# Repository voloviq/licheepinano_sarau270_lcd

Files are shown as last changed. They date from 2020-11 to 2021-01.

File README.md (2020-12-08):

# licheepinano_sarau270_lcd
LicheePi Nano Sara U270 Development Board

3D View of Board

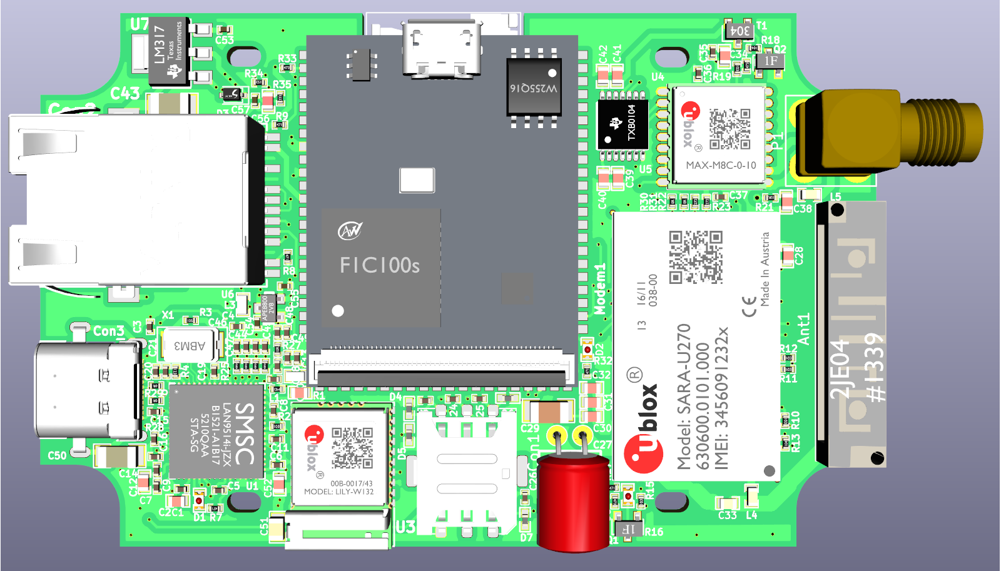
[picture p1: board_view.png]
3D View


PCB footprint is desinged for R19-2 SCI package

https://www.tme.eu/pl/details/absp-19/obudowy-uniwersalne/sci/r19-2/

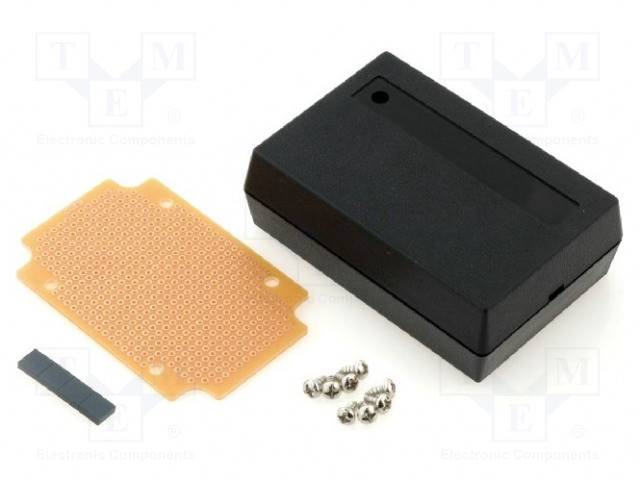
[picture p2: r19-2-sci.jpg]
Package


### Limitation

GSM antenna is not well designed. In this pcb footprint it can be difficult or impossible to do it well. To achieve maximum performance use SMD connector with external antenna.

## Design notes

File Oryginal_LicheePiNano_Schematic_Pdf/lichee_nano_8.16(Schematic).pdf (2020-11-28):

LCD | DDR | CSI

## SDC0

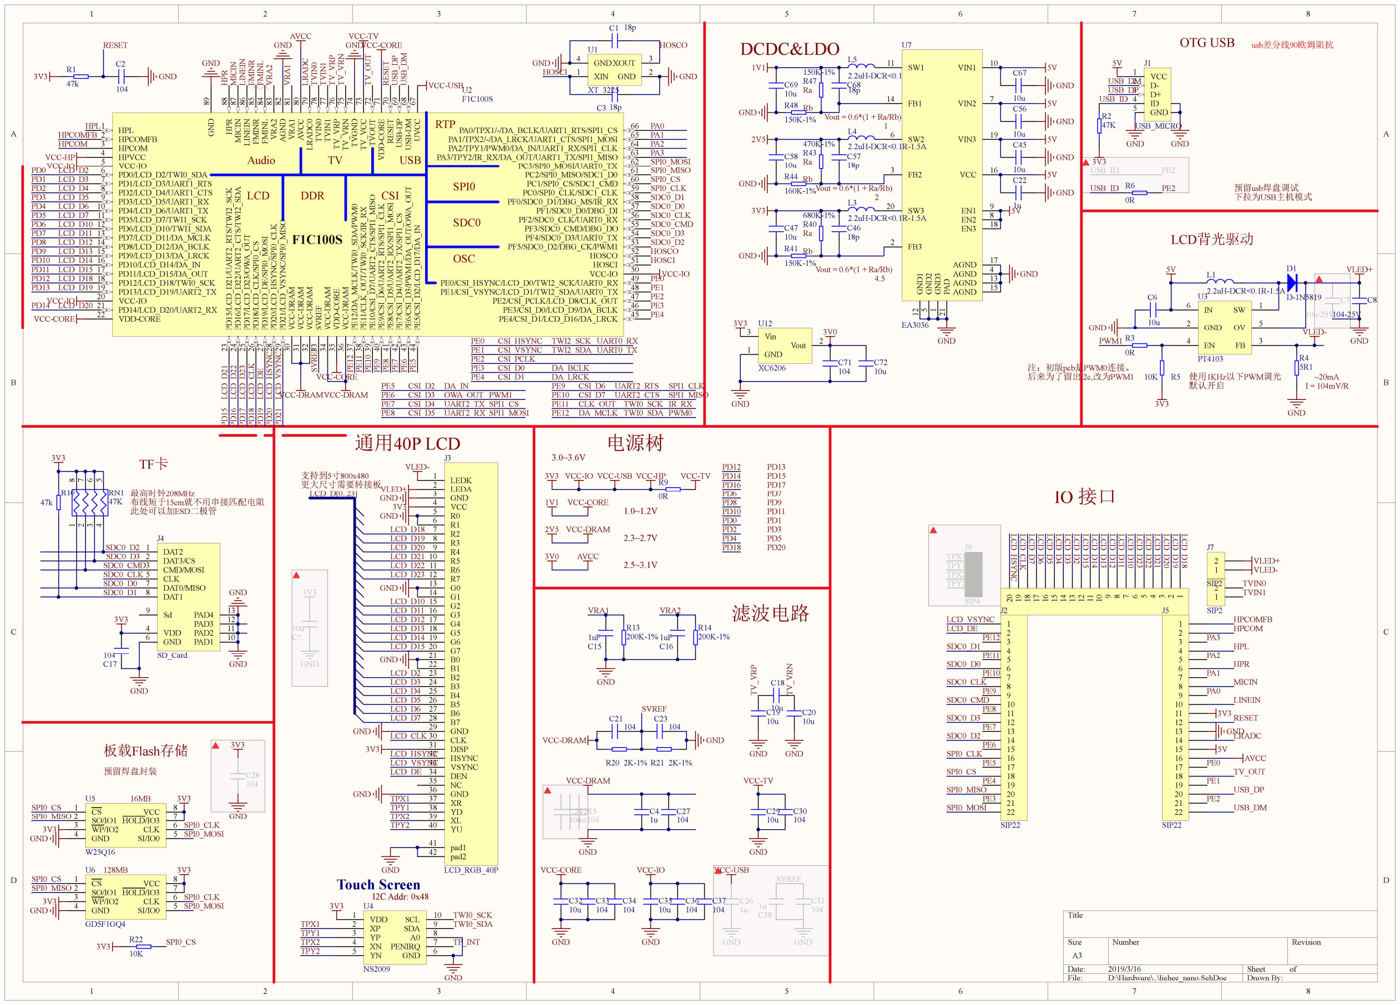
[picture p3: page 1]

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
Title

Size | Number | | Revision
A3
Date: | 2019/3/16 | Sheet | of
File: | D:\Hardware\..\lichee_nano.SchDoc | Drawn By:

HPL 1
HPCOMFB 2
HPCOM 3
HPVCC 4
VCC-IO 5
PD0/LCD_D2/TWI0_SDA 6
PD1/LCD_D3/UART1_RTS 7
PD2/LCD_D4/UART1_CTS 8
PD3/LCD_D5/UART1_RX 9
PD4/LCD_D6/UART1_TX 10
PD5/LCD_D7/TWI1_SCK 11
PD6/LCD_D10/TWI1_SDA 12
PD7/LCD_D11/DA_MCLK 13
PD8/LCD_D12/DA_BCLK 14
PD9/LCD_D13/DA_LRCK 15
PD10/LCD_D14/DA_IN 16
PD11/LCD_D15/DA_OUT 17
PD12/LCD_D18/TWI0_SCK 18
PD13/LCD_D19/UART2_TX 19
VCC-IO 20
PD14/LCD_D20/UART2_RX 21
VDD-CORE 22 | PD¹⁵/LCD_D²¹/UART²_RTS/TWI2_SCK 23 PD¹⁶/LCD_D²²/UART²_CTS/TWI2_SDA 24 PD¹⁷/LCD_D²³/OWA_OUT 25 PD¹⁸/LCD_CLK/SPI0_CS 26 PD¹⁹/LCD_DE/SPI0_MOSI 27 PD²⁰/LCD_HSYNC/SPI0_CLK 28 PD²¹/LCD_VSYNC/SPI0_MISO 29 VCC⁻DRAM 30 VCC⁻DRAM 31 VCC⁻DRAM 32 SVREF 33 VCC⁻DRAM 34 VDD⁻CORE 35 VCC⁻DRAM 36 PE¹²/DA_MCLK/TWI0_SDA/PWM⁰ 37 PE¹¹/CLK_OUT/TWI0_SCK/IR_RX 38 PE¹⁰/CSI_D⁷/UART²_CTS/SPI1_MISO 39 PE⁹/CSI_D⁶/UART²_RTS/SPI1_CLK 40 PE⁸/CSI_D⁵/UART²_RX/SPI1_MOSI 41 PE⁷/CSI_D⁴/UART²_TX/SPI1_CS 42 PE⁶/CSI_D³/PWM¹/DA_OUT/OWA_OUT 43 PE⁵/CSI_D²/LCD_D¹⁷/DA_IN 44
PE4/CSI_D1/LCD_D16/DA_LRCK | 45 PE3/CSI_D0/LCD_D9/DA_BCLK | 46 PE2/CSI_PCLK/LCD_D8/CLK_OUT | 47 PE1/CSI_VSYNC/LCD_D1/TWI2_SDA/UART0_TX | 48 PE0/CSI_HSYNC/LCD_D0/TWI2_SCK/UART0_RX | 49 VCC-IO | 50 HOSCI | 51 HOSCO | 52 PF5/SDC0_D2/DBG_CK/PWM1 | 53 PF4/SDC0_D3/UART0_TX | 54 PF3/SDC0_CMD/DBG_DO | 55 PF2/SDC0_CLK/UART0_RX | 56 PF1/SDC0_D0/DBG_DI | 57 PF0/SDC0_D1/DBG_MS/IR_RX | 58 PC0/SPI0_CLK/SDC1_CLK | 59 PC1/SPI0_CS/SDC1_CMD | 60 PC2/SPI0_MISO/SDC1_D0 | 61 PC3/SPI0_MOSI/UART0_TX | 62 PA3/TPY2/IR_RX/DA_OUT/UART1_TX/SPI1_MISO | 63 PA2/TPY1/PWM0/DA_IN/UART1_RX/SPI1_CLK | 64 PA1/TPX2/-/DA_LRCK/UART1_CTS/SPI1_MOSI | 65 PA0/TPX1/-/DA_BCLK/UART1_RTS/SPI1_CS | 66 UVCC ⁶⁷ USB⁻DM ⁶⁸ USB⁻DP ⁶⁹ RESET ⁷⁰ VDD⁻CORE ⁷¹ TVOUT ⁷² TV_VCC ⁷³ TVGND ⁷⁴ TV_VRN ⁷⁵ TV_VRP ⁷⁶ TVIN¹ ⁷⁷ TVIN⁰ ⁷⁸ LRADC⁰ ⁷⁹ AVCC ⁸⁰ VRA¹ ⁸¹ AGND ⁸² VRA² ⁸³ FMINL ⁸⁴ FMINR ⁸⁵ LINEIN ⁸⁶ MICIN ⁸⁷ HPR ⁸⁸ GND ⁸⁹

## OSC

## SPI0

## RTP

Audio | TV | USB

## F1C100S

U2
F1C100S

LEDK 1
LEDA 2
GND 3
VCC 4
R0 5
R1 6
R2 7
R3 8
R4 9
R5 10
R6 11
R7 12
G0 13
G1 14
G2 15
G3 16
G4 17
G5 18
G6 19
G7 20
B0 21
B1 22
B2 23
B3 24
B4 25
B5 26
B6 27
B7 28
GND 29
CLK 30
DISP 31
HSYNC 32
VSYNC 33
DEN 34
NC 35
GND 36
XR 37
YD 38
XL 39
YU 40

pad1 41
pad2 42

J3

LCD_RGB_40P

LCD_D2
LCD_D3
LCD_D4
LCD_D5
LCD_D6
LCD_D7

LCD_D10
LCD_D11
LCD_D12
LCD_D13
LCD_D14
LCD_D15

LCD_D18
LCD_D19
LCD_D20
LCD_D21
LCD_D22
LCD_D23

LCD_D[0..23] GND

3V3

GND

C?

10u

LCD_CLK

LCD_DE

LCD_HSYNC
LCD_VSYNC

TPX1

TPX2

TPY1

TPY2

GND

GND

VLED+

VLED-

# 通用40P LCD

GND

GND

GND

3V3

3V3

GND

支持到5寸800x480
更大尺寸需要转接板

LCD_D2
LCD_D3
LCD_D4
LCD_D5
LCD_D6
LCD_D7
LCD_D10
LCD_D11
LCD_D12
LCD_D13
LCD_D14
LCD_D15
LCD_D18
LCD_D19
LCD_D20 | LCD_D²¹ LCD_D²² LCD_D²³ LCD_CLK LCD_DE LCD_HSYNC LCD_VSYNC

VCC-IO

VCC-IO

VCC-IO

VCC-CORE

VCC-CORE

VCC-DRAMVCC-DRAM SVREF

VCC-CORE RESET USB_DP USB_DMGND

VCC-HP

HPL | HPR MICIN LINEIN FMINR FMINL VRA² | VRA¹ AVCCLRADC TVIN⁰ TVIN¹ TV_VRP TV_VRN

VCC-TVTV_OUT

PE0
PE1
PE2
PE3

PE4 PE¹² PE¹¹ PE¹⁰ PE⁹ PE⁸ PE⁷ PE⁶ PE⁵

HOSCO
HOSCI

SDC0_D0

SDC0_D1

SDC0_D2

SDC0_D3

SDC0_CLK
SDC0_CMD

SPI0_CLK

SPI0_CS

SPI0_MISO

SPI0_MOSI

HPCOMFB
HPCOM
XIN 1 | GND | 2
XOUT | 3 GND 4

U1

XT_3225

GND
GND

C3 18p

C1 18p

HOSCO

HOSCI

SDC0_CMD
SDC0_CLK
SDC0_D0
SDC0_D1

SDC0_D2
SDC0_D3

GND

GND

3V3

C17

104 ¹

2

34 58
7

6
RN1
47K

R10
47k

3V3

最高时钟208MHz
布线短于15cm就不用串接匹配电阻
此处可以加ESD二极管

## TF卡

GND

CS 1
SO/IO1 2
WP/IO2 3
GND 4 | SI/IO0 | 5
| CLK | 6
HOLD/IO3 | 7
VCC | 8

U5

W25Q16

SPI0_MISO

SPI0_MOSI

SPI0_CLK

SPI0_CS

CS 1
SO/IO1 2
WP/IO2 3
GND 4 | SI/IO0 | 5
| CLK | 6
HOLD/IO3 | 7
VCC | 8

U6

GD5F1GQ4

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
3V3 | SPI0_CS

16MB

128MB

## 板载Flash存储

预留焊盘封装

# DCDC&LDO

SW 1

GND 2

FB | 3 EN 4
OV | 5

IN 6

U3

PT4103

L1
2.2uH-DCR<0.1R-1.5A
C6

10u GND

D1

D-1N5819 C7

10u-25V

C8

| 104-25V VLED+

GND

10K R5
I = 104mV/R

R4
5R1

GND

VLED-

使用1KHz以下PWM调光 | ~20mA

## LCD背光驱动

5V

PWM1 R3
0R

R2
47K

usb差分线90欧姆阻抗

VCC 1
D- 2
D+ 3
ID 4
GND 5

J1

USB_MICRO

GND GND

USB_ID

预留usb焊盘调试
下拉为USB主机模式

# 电源树

3V3 VCC-IO

GND | GND

VCC-TV

1V1 VCC-CORE
1.0~1.2V

3.0~3.6V

VCC-USB

VCC-USB

2V5 VCC-DRAM
2.3~2.7V

3V0 AVCC
2.5~3.1V

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
PD10
PD11
PD12
PD13
PD14 | PD¹⁵ PD¹⁶ PD¹⁷ PD¹⁸ PD¹⁹ PD²⁰ PD²¹
PD0 | PD1
PD2 | PD3
PD4 | PD5
PD6 | PD7
PD8 | PD9
PD10 | PD11
PD12 | PD13
PD14 | PD15
PD16 | PD17

C2

104

3V3 | GND

RESET

GND

C15

1uF

R13
200K-1%
VRA1 | VRA2

C16

1uF

R14
200K-1%

R20 2K-1% R21 2K-1%

C21
104

C23
104
VCC-DRAM | GND

SVREF

SVREF

C31
104 C38

1u

GND

VCC-DRAM

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
VCC-CORE

C32
10u

C33
104

C34
104

GND

VCC-IO

C35
10u

C36
104

C37
104

GND

VCC-TV

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
GND | GND TV_VRP | TV_VRN

## OTG USB

# 滤波电路

# IO 接口

USB_DP

USB_DM

VCC-HP

R1
47k

R9
0R

SPI0_MISO

SPI0_MOSI

SPI0_CLK

SPI0_CS

1V1 | 5V

L5

# 2.2uH-DCR<0.1R-1.5A GND³

1

FB3 2

FB2 3

AGND 4 GND²

5

SW2 6

VIN2 | 7
EN2 | 8
EN1 | 9
VIN1 | 10 SW1 11 | GND¹ 12
AGND | 13

FB1 14

AGND | 15
VCC | 16
AGND | 17
EN3 | 18
VIN3 | 19
SW3 20 | PAD 21

U7

EA3036

R47

150K-1%
GND

C67

10u

C68 18p C69
10u Ra
5V Rb GND
GND Vout = 0.6*(1 + Ra/Rb)

C56

10u

R48
150K-1%
1
2V5 | 5V

L4
2.2uH-DCR<0.1R-1.5A
R43

470K-1%
GND

C45

10u

C57
18p

C58
10u Ra
5V Rb GND | Vout = 0.6*(1 + Ra/Rb) | GND
C22

1u

R44
160K-1%
2
3V3 | 5V

L3
2.2uH-DCR<0.1R-1.5A
R40

680K-1%
C46
18p

C47
10u Ra

Rb GND

R41
150K-1%
GND Vout = 0.6*(1 + Ra/Rb) 4.5

GND

3V0

C71
104

Vin 3

GND 1

Vout 2

U12

XC6206

3V3

C72
10u

GND

C26
1u

GND

VCC-USB

3V3

C28
104

GND

3V3 20 | 119 | 218 | 317 | 416 | 515 | 614 | 713 | 812 | 91110

J8

# SIP20LCD_HSYNC LCD_CLK

LCD_DE

LCD_VSYNC | LCD_D7 LCD_D6 LCD_D5 LCD_D4 LCD_D3 LCD_D2 LCD_D15 LCD_D14 LCD_D13 LCD_D12 LCD_D11 LCD_D10 LCD_D23 LCD_D22 LCD_D21 LCD_D20 LCD_D19 LCD_D18 PD18 | PD20

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
PE10
PE11
PE12

CSI_HSYNC TWI2_SCK UART0_RX CSI_VSYNC TWI2_SDA UART0_TX CSI_PCLK
CSI_D0
CSI_D1
CSI_D2
CSI_D3
CSI_D4
CSI_D5

CSI_D6
CSI_D7

DA_MCLK

CLK_OUT

DA_BCLK
DA_LRCK
DA_IN
OWA_OUT
UART2_TX SPI1_CS
UART2_RX SPI1_MOSI

UART2_RTS SPI1_CLK
UART2_CTS SPI1_MISO
TWI0_SCK
TWI0_SDA

IR_RX
PWM0

3V3

默认开启

PA0
PA1
PA2
PA3

USB_ID R6
0R

PE2

USB_ID | PE2

PE5

PE6

PE7

PE8

PE9

PE10

PE11

PE12

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
SDC0_D0

SDC0_D1

SDC0_D2

SDC0_D3

SDC0_CLK

SDC0_CMD

SPI0_CLK

SPI0_CS

SPI0_MISO

SPI0_MOSI

HPL

HPCOMFB
HPCOM

RESET

USB_DP

USB_DM

HPR

MICIN

LINEIN

AVCC

LRADC

TVIN0
TVIN1

TV_OUT

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
SIP22

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
SIP22

DAT2 1
DAT3/CS 2
CMD/MOSI 3

VDD 4

CLK 5

GND 6

DAT0/MISO 7
DAT1 8

Sd 9

PAD1 | 10 PAD2 | 11 PAD3 | 12 PAD4 | 13

J4

SD_Card

1

2

J6

SIP2

1

2

J7

SIP2

VLED+
VLED-

1

2

3

4

J9

SIP4

TPX1

TPX2

TPY1

TPY2

PWM1

注：初版pcb是PWM0连接。
后来为了留出i2c,改为PWM1

# Touch Screen

TP_INT

I2C Addr: 0x48

VDD 1
XP 2
YP 3
XN 4
YN 5 | GND | 6
| PENIRQ | 7
| A0 | 8
SDA | 9
SCL | 10

U4

NS2009

3V3

TPX1
TPY1
TPX2

GND

TPY2

TWI0_SCK
TWI0_SDA

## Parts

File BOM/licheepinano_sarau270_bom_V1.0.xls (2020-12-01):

Component | Description | Part | References | Value | Footprint | Quantity Per PCB | Notice | Supplier Part Number | Supplier | URL | Manufacturer Part Number | Manufacturer | LCSC Part # (optional)
1 | Embedded Dielectric Quad Band Antenna | MEE04 | Ant1 | MEE04 | MEE04 | 1 |  | MEE04 | Microdis
2 | 100nF, 16V, X5R, 10%, -40°C to +85°C | 100nF/16V | C52 | 100nF/16V | 0603 | 1
3 | 100nF, 50V, X5R, 10%, -40°C to +85°C | 100nF/50V | C2 C5 C6 C8 C9 C11 C12 C13 C14 C15 C16 C17 C18 C19 C20 C21 C35 C36 C37 | 100nF/50V | 0402 | 19 |  | CL05B104KO5NNNC | TME | https://www.tme.eu/pl/details/cl05b104ko5nnnc/kondensatory-mlcc-smd-0402/samsung/ | CL05B104KO5NNNC | SAMSUNG
4 | 100nF, 50V, X5R, 10%, -40°C to +85°C | 100nF/50V | C28 C30 C31 C32 C40 C42 | 100nF/50V | 0603 | 6 |  | CL10B104JB8NNNC | TME | https://www.tme.eu/pl/details/cl10b104jb8nnnc/kondensatory-mlcc-smd-0603/samsung/ | CL10B104JB8NNNC | SAMSUNG
5 | 10pF, 50V, X5R, 10%, -40°C to +85°C | 10pF/50V | C33 | 10pF/50V | 0603 | 1 |  | CL10C100JB8NNNC | TME | https://www.tme.eu/pl/details/cl10c100jb8nnnc/kondensatory-mlcc-smd-0603/samsung/ | CL10C100JB8NNNC | SAMSUNG
6 | 10uF, 10V, X5R, 10%, -40°C to +85°C | 10uF/10V | C56 | 10uF/10V | 0603 | 1 |  | C0603C106M9PAC | TME | https://www.tme.eu/pl/details/c0603c106m9pac/kondensatory-mlcc-smd-0603/kemet/c0603c106m9pactu/ | C0603C106M9PACTU | KEMET | C162265
7 | 10uF, 16V, X5R, 10%, -40°C to +85°C | 10uF/16V | C51 | 10uF/16V | 0805 | 1
8 | 15pF, 50V, X5R, 10%, -40°C to +85°C | 15pF/50V | C44 C45 C46 C47 | 15pF/50V | 0402 | 4 |  | GRM1555C1H150JA01D | TME | https://www.tme.eu/pl/details/grm1555c1h150ja01d/kondensatory-mlcc-smd-0402/murata/ | GRM1555C1H150JA01D | MURATA
9 | 1nF, 2kV, X7R, 10%, -40°C to +85°C | 1nF/2kV | C43 C50 | 1nF/2kV | 1206 | 2 |  | CC1206KKX7RD102 | TME | https://www.tme.eu/pl/details/cc1206kkx7rd102/kondensatory-mlcc-smd-1206/yageo/cc1206kkx7rdbb102/ | CC1206KKX7RDBB102 | YAGEO
10 | 1uF, 10V, X5R, 10%, -40°C to +85°C | 1uF/10V | C53 C54 C55 C57 | 1uF/10V | 0402 | 4 |  | CL05A105KP5NNNC | TME | https://www.tme.eu/pl/details/cl05a105kp5nnnc/kondensatory-mlcc-smd-0402/samsung/ | CL05A105KP5NNNC | SAMSUNG
11 | 1uF, 6.3V, X5R, 10%, -40°C to +85°C | 1uF/6.3V | C10 C34 C38 C39 C41 | 1uF/6V3 | 0603 | 5 |  | CL10B105KO8NNNC | TME | https://www.tme.eu/pl/details/cl10b105ko8nnnc/kondensatory-mlcc-smd-0603/samsung/ | CL10B105KO8NNNC | SAMSUNG
12 | 220uF, 6.3, -40°C to +85°C, Polymer Capacitor | 220uF/6.3V | C27 | 220uF/6V3 | Fi 8mm x length 8mm | 1 |  | 710-870025174002 | Mouser | https://pl.mouser.com/ProductDetail/Wurth-Elektronik/870025174002?qs=0KOYDY2FL28WZrZvNjpH0g%3D%3D | 870025174002 | Wurth Elektronik
13 | 22nF, 25V, X5R, 10%, -40°C to +85°C | 22nF/25v | C48 C49 | 22nF/25V | 0402 | 2 |  | GRM155R71E223KA61D | TME | https://www.tme.eu/pl/details/grm155r71e223ka61d/kondensatory-mlcc-smd-0402/murata/ | GRM155R71E223KA61D | MURATA
14 | 30pF, 50V, X5R, 10%, -40°C to +85°C | 30pF/50V | C3 C4 | 30pF/50V | 0402 | 2 |  | C0402C300J5GAC | TME | https://www.tme.eu/pl/details/c0402c300j5gac/kondensatory-mlcc-smd-0402/kemet/c0402c300j5gactu/ | C0402C300J5GACTU | KEMET
15 | 4.7uF, 6.3V, X5R, 10%, -40°C to +85°C | 4.7uF/6.3V | C1 C7 | 4.7uF/6V3 | 0603 | 2 |  | CL10A475KQ8NNNC | TME | https://www.tme.eu/pl/details/cl10a475kq8nnnc/kondensatory-mlcc-smd-0603/samsung/ | CL10A475KQ8NNNC | SAMSUNG
16 | 47pF, 50V, X5R, 10%, -40°C to +85°C | 47pF/50V | C23 C24 C25 C26 | 47pF/50V | 0402 | 4 |  | 0402N470J500CT | TME | https://www.tme.eu/pl/details/0402n470j500ct/kondensatory-mlcc-smd-0402/walsin/ | 0402N470J500CT | WALSIN
17 | 47uF, 6.3V, X5R, 20%, -40°C to +85°C MLCC | 47uF/6.3V | C29 | 47uF/6V3 | 1206 | 1 |  | 810-C3216X5R0J476M | Mouser | https://pl.mouser.com/ProductDetail/TDK/C3216X5R0J476M160AC?qs=sGAEpiMZZMvsSlwiRhF8qsDt8B2LujiHL4PsWRWliZg%3D | C3216X5R0J476M160AC | TDK
18 | GCT Nano SIM Holder 6 contacts | SIM8050-6-0-14-01-A | Con1 | SIM8050-6-0-14-01-A | SMD Nano Siim | 1 |  | 2344457 | Farnell | https://uk.farnell.com/gct-global-connector-technology/sim8050-6-0-14-01-a/connector-nano-sim-card-6pos-smt/dp/2344457 | SIM8050-6-0-14-01-A. | GCT (GLOBAL CONNECTOR TECHNOLOGY)
19 | WR-COM USB 3.1 Type C Receptacle Horizontal Mid-Mount THR / SMT 1.6 mm | USB C | Con3 | USB_C_Wurth_632723130112 | USB_C | 1 |  | 710-632723130112 | Mouser | https://pl.mouser.com/ProductDetail/Wurth-Elektronik/632723130112?qs=2WXlatMagcEknienHxbwUw%3D%3D | 632723130112 | Wurth Elektronik
20 | LAN-Transformer WE-RJ45LAN 10/100BaseT - 40°C to + 85°C | WE-RJ45 | Con2 | WE-RJ45_7498011122AR | WE-RJ45 | 1 |  | 710-7498011122AR | Mouser | https://pl.mouser.com/ProductDetail/Wurth-Elektronik/7498011122AR?qs=GBLSl2AkiruAAlB45OgRtA%3D%3D | 7498011122AR | Wurth
21 | Red Led diode 630nm 20mA 200...350mcd 120° -40°C to +85°C | KPG-1608SURKC-T | D1 D2 D8 | KPG-1608SURKC-T | 0603 | 3 |  | KPG-1608SURKC-T | TME | https://www.tme.eu/pl/details/kpg-1608surkc-t/diody-led-smd-kolorowe/kingbright-electronic/ | KPG-1608SURKC-T | KINGBRIGHT ELECTRONIC
22 | Schottky Barrier Diode 500mA | NSR0530H-D | D3 | NSR0530H-D | SOD323 | 1
23 | ESD Protector, Overvoltage Protection Device | PESD0402-140 | D4 D5 D6 D7 | PESD0402-140 | 0402 | 4 |  | 650-PESD0402-140 | Mouser | https://pl.mouser.com/ProductDetail/Littelfuse/PESD0402-140?qs=y1EbU1W0OrtTHVfbQV6MTg%3D%3D | PESD0402-140 | Littelfuse
24 | LiangHaoCai 2.4" LED Display with SPI Interface | LiangHaoCai Display | DIS1 | LiangHaoCai_Ili9341_spi | Ffc/Fpc solder type | 1
25 | 39nH, 300mA, 0.6Ω, 10%, -40°C to +85°C | 39nH | L4 L5 | 39nH | 0603 | 2 |  | 963-HK160839NH-T | Mouser | https://pl.mouser.com/ProductDetail/Taiyo-Yuden/HK160839NH-T | HK160839NH-T | Taiyo Yuden
26 | Z=600Ohm,Load=0.3A,R=0.7Ohm, Temp=-55C+125C, EMI Suppression Filters EMIFIL | BLM15HG601SN1D | L6 | BLM15HG601SN1D | 0402 | 1
27 | Ferrite Bead 600Ω 1A 200mΩ - 55℃ +125℃ 0603 | LCBA-601 | L1 L3 | LCBA-601 | LCBA-601 | 2 |  | LCBA-601 | TME | https://www.tme.eu/pl/details/lcba-601/ferryty-koraliki/ferrocore/ | LCBA-601 | FERROCORE
28 | SARA-U2 series 3.75G HSPA Cellular Modules | Sara_U270 | Modem1 | Sara_U270 | LGA | 1
29 | Adam Tech SMA Jack Right Angle THT Connector | RF2-03E-T-00-50-G | P1 | RF2-03E-T-00-50-G | THT-SMA | 1 |  | RF2-03E-T-00-50-G | TME | https://www.tme.eu/pl/details/rf2-03e-t-00-50-g/zlacza-sma-smb-smc/adam-tech/ | RF2-03E-T-00-50-G | ADAM TECH
30 | UCE=45V, Ic=100mA, P=250mW, -40°C to +85°C NPN Transistor | BC847B | Q1 Q2 | BC847B | SOT23 | 2 |  | BC847BE6327 | TME | https://www.tme.eu/pl/details/bc847be6327/tranzystory-npn-smd/infineon-technologies/ | BC847BE6327 | INFINEON TECHNOLOGIES
31 | 0Ω 0.063W, 10%, -40°C to +85°C | 0R | R28 R29 R30 R31 | 0R | 0402 | 4 | R30, R31 Not mount | CRCW04020000Z0E | TME | https://www.tme.eu/pl/details/crcw04020000z0e/rezystory-smd-0402/vishay/crcw04020000z0ed/ | CRCW04020000Z0ED | VISHAY | C325378
32 | 100kΩ 0.063W, 10%, -40°C to +85°C | 100k | R13 R18 | 100k | 0402 | 2 |  | RC0402FR-07100K | TME | https://www.tme.eu/pl/details/rc0402fr-07100k/rezystory-smd-0402/yageo/ | RC0402FR-07100K | YAGEO
33 | 10Ω 0.063W, 10%, -40°C to +85°C | 10R | R21 R27 | 10R | 0402 | 2 |  | SMD0402-10R-1% | TME | https://www.tme.eu/pl/details/smd0402-10r-1%2525/rezystory-smd-0402/royal-ohm/0402wgf100jtce/ | 0402WGF100JTCE | ROYAL OHM
34 | 10kΩ 0.063W, 10%, -40°C to +85°C | 10k | R2 R10 R11 R12 R15 R19 | 10k | 0402 | 6 |  | SMD0402-10K-1% | TME | https://www.tme.eu/pl/details/smd0402-10k-1%2525/rezystory-smd-0402/royal-ohm/0402wgf1002tce/ | 0402WGF1002TCE | ROYAL OHM
35 | 12.4kΩ 1% 0.063W, 10%, -40°C to +85°C | 12k4 | R1 | 12k/1% | 0402 | 1 |  | 603-RC0402FR-0712K4L | Mouser | https://pl.mouser.com/ProductDetail/Yageo/RC0402FR-0712K4L | RC0402FR-0712K4L | Yageo
36 | 12kΩ 1% 0.063W, 10%, -40°C to +85°C | 12k | R4 | 12k/1% | 0402 | 1 |  | 279-CRGCQ0402F12K | Mouser | https://pl.mouser.com/ProductDetail/TE-Connectivity-Holsworthy/CRGCQ0402F12K | CRGCQ0402F12K | TE Connectivity / Holsworthy
37 | 1MΩ 0.063W, 10%, -40°C to +85°C | 1M | R3 | 1M | 0402 | 1 |  | SMD0402-1M-1% | TME | https://www.tme.eu/pl/details/smd0402-1m-1%2525/rezystory-smd-0402/royal-ohm/0402wgf1004tce/ | 0402WGF1004TCE | ROYAL OHM
38 | 1.5kΩ 0.063W, 10%, -40°C to +85°C | 1k5 | R34 | 1k5 | 0402 | 1 |  | SMD0402-1K5-1% | TME | https://www.tme.eu/pl/details/smd0402-1k5-1%2525/rezystory-smd-0402/royal-ohm/0402wgf1501tce/ | 0402WGF1501TCE | ROYAL OHM
39 | 2.7kΩ 0.063W, 10%, -40°C to +85°C | 2k7 | R22 R23 | 2k7 | 0402 | 2 |  | CRCW04022K70FKTDBC | TME | https://www.tme.eu/pl/details/crcw04022k70fktdbc/rezystory-smd-0402/vishay/ | CRCW04022K70FKTDBC | VISHAY
40 | 4.7kΩ 0.063W, 10%, -40°C to +85°C | 3k3 | R35 | 3k3 | 0402 | 1 |  | SMD0402-3K3-1% | TME | https://www.tme.eu/pl/details/smd0402-3k3-1%2525/rezystory-smd-0402/royal-ohm/0402wgf3301tce/ | 0402WGF3301TCE | ROYAL OHM
41 | 470Ω 0.063W, 10%, -40°C to +85°C | 470R | R7 R8 R9 R17 R32 | 470R | 0402 | 5 |  | SMD0402-470R-1% | TME | https://www.tme.eu/pl/details/smd0402-470r-1%25/rezystory-smd-0402/royal-ohm/0402wgf4700tce/ | 0402WGF4700TCE | ROYAL OHM
42 | 47kΩ 0.063W, 10%, -40°C to +85°C | 47k | R16 R20 R33 | 47k | 0402 | 3 |  | CQ0402-47K-1% | TME | https://www.tme.eu/pl/details/cq0402-47k-1%2525/rezystory-smd-0402/royal-ohm/cq02wgf4702tce/ | CQ02WGF4702TCE | ROYAL OHM
43 | 49.9Ω 1% 0.063W, 10%, -40°C to +85°C | 49R9 | R14 R24 R25 R26 | 49R9/1% | 0402 | 4
44 | LicheePiNano board | LicheePiNano | SOM1 | LicheePiNano | SOM | 1 |  | LicheePi Nano | Seeed | https://www.seeedstudio.com/LicheePi-Nano-ARM926EJS-SoC-Development-Board-16M-Flash-p-2892.html | LicheePi Nano | SiPeed
45 | Uds=-20V; Id=-2,4A; 0,5W P-Channel Specified PowerTrench MOSFET | FDN304P | T1 | FDN304P | SOT23 | 1 |  | 512-FDN304P | Mouser | https://pl.mouser.com/ProductDetail/ON-Semiconductor-Fairchild/FDN304P?qs=GeD7q9OHBPxvyy2Fqp9AhQ%3D%3D | FDN304P | ON Semiconductor
46 | 2,8V / 0,4A Low Dropout Positive Voltage Regulators | AP2127K-2.8TRG1 | U6 | AP2127K-2.8TRG1 | SOT23 | 1 |  | AP2127K-2.8TRG1 | TME | https://www.tme.eu/pl/details/ap2127k-2.8trg1/stabilizatory-napiecia-nieregulowane-ldo/diodes-incorporated/ | AP2127K-2.8TRG1 | Diodes Incorporated | C236686
47 | USB 2.0 Hub and 10/100 Ethernet Controller | LAN9514I | U1 | LAN9514I | TQFP64 | 1 |  | 886-LAN9514I-JZX | Mouser | https://pl.mouser.com/ProductDetail/Microchip-Technology/LAN9514I-JZX?qs=pA5MXup5wxEv6pMvgbni8Q%3D%3D | LAN9514I-JZX | Microchip Technology
48 | LILY-W1 series Host-based Wi-Fi modules | LILY-W132 | U3 | LILY-W132 | SMD 14 mm x 10 mm x 3.84 mm | 1
49 | 1.5A LM317 3-Terminal Adjustable Regulator | LM317DCYR | U7 | LM317DCYR | SOT223 | 1 |  | 595-LM317DCYR | Mouser | https://pl.mouser.com/ProductDetail/Texas-Instruments/LM317DCYR?qs=YhsVCygOPE0H9jB5Yaa05Q%3D%3D | LM317DCYR | Texas Instruments | C51466
50 | u-blox M8 concurrent GNSS modules | MAX-M8C | U4 | MAX-M8C | SMD 9.7 x 10.1 x 2.5 mm | 1
51 | 4-Bit Bidirectional Voltage-level Translator With Automatic Direction Sensing and ±15-kV ESD Protection | TXB0104 | U5 | TXB0104 | TSSOP14 | 1 |  | 595-TXB0104PWR | Mouser | https://pl.mouser.com/ProductDetail/Texas-Instruments/TXB0104PWR?qs=oFXvjAmG9EjSF69GpMWq5w%3D%3D | TXB0104PWR | Texas Instruments | C60708
52 | 25 MHz SMD Crystal Resonator | ABM3-25.000MHZ-D2Y-T | X1 | ABM3-25.000MHZ-D2Y-T | SMD 5 mm x 3.2 mm | 1 |  | 815-ABM3-25-D2Y-T | Mouser | https://pl.mouser.com/ProductDetail/ABRACON/ABM3-25000MHZ-D2Y-T?qs=ihRgKfnEsN6FZPAss%252Bj6lw%3D%3D | ABM3-25.000MHZ-D2Y-T | ABRACON

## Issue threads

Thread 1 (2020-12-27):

Problem with LicheePi Nano footprint

voloviq, 2020-12-27:
After receiving the PCB board discover that the touchscreen driver located on the LicheePi Nano board not match the mainboard PCB window. Additionally, the soldering points of sd-card on LicheePi Nano are in a collision with the mainboard PCB.

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

Suggestion:

Correct LicheePi Nano footprint according to the above.

voloviq, 2021-01-03:
Corrected footprint

Closed 2021-01-03.

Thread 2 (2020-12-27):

PCB edge layout too big to final package

voloviq, 2020-12-27:
When trying to figurate board into package discover that board is too big into the package.

Suggestion:
Reduce 0.5mm on each angle.

voloviq, 2021-01-03:
After measurements reduced from each side 0.25mm

Closed 2021-01-03.

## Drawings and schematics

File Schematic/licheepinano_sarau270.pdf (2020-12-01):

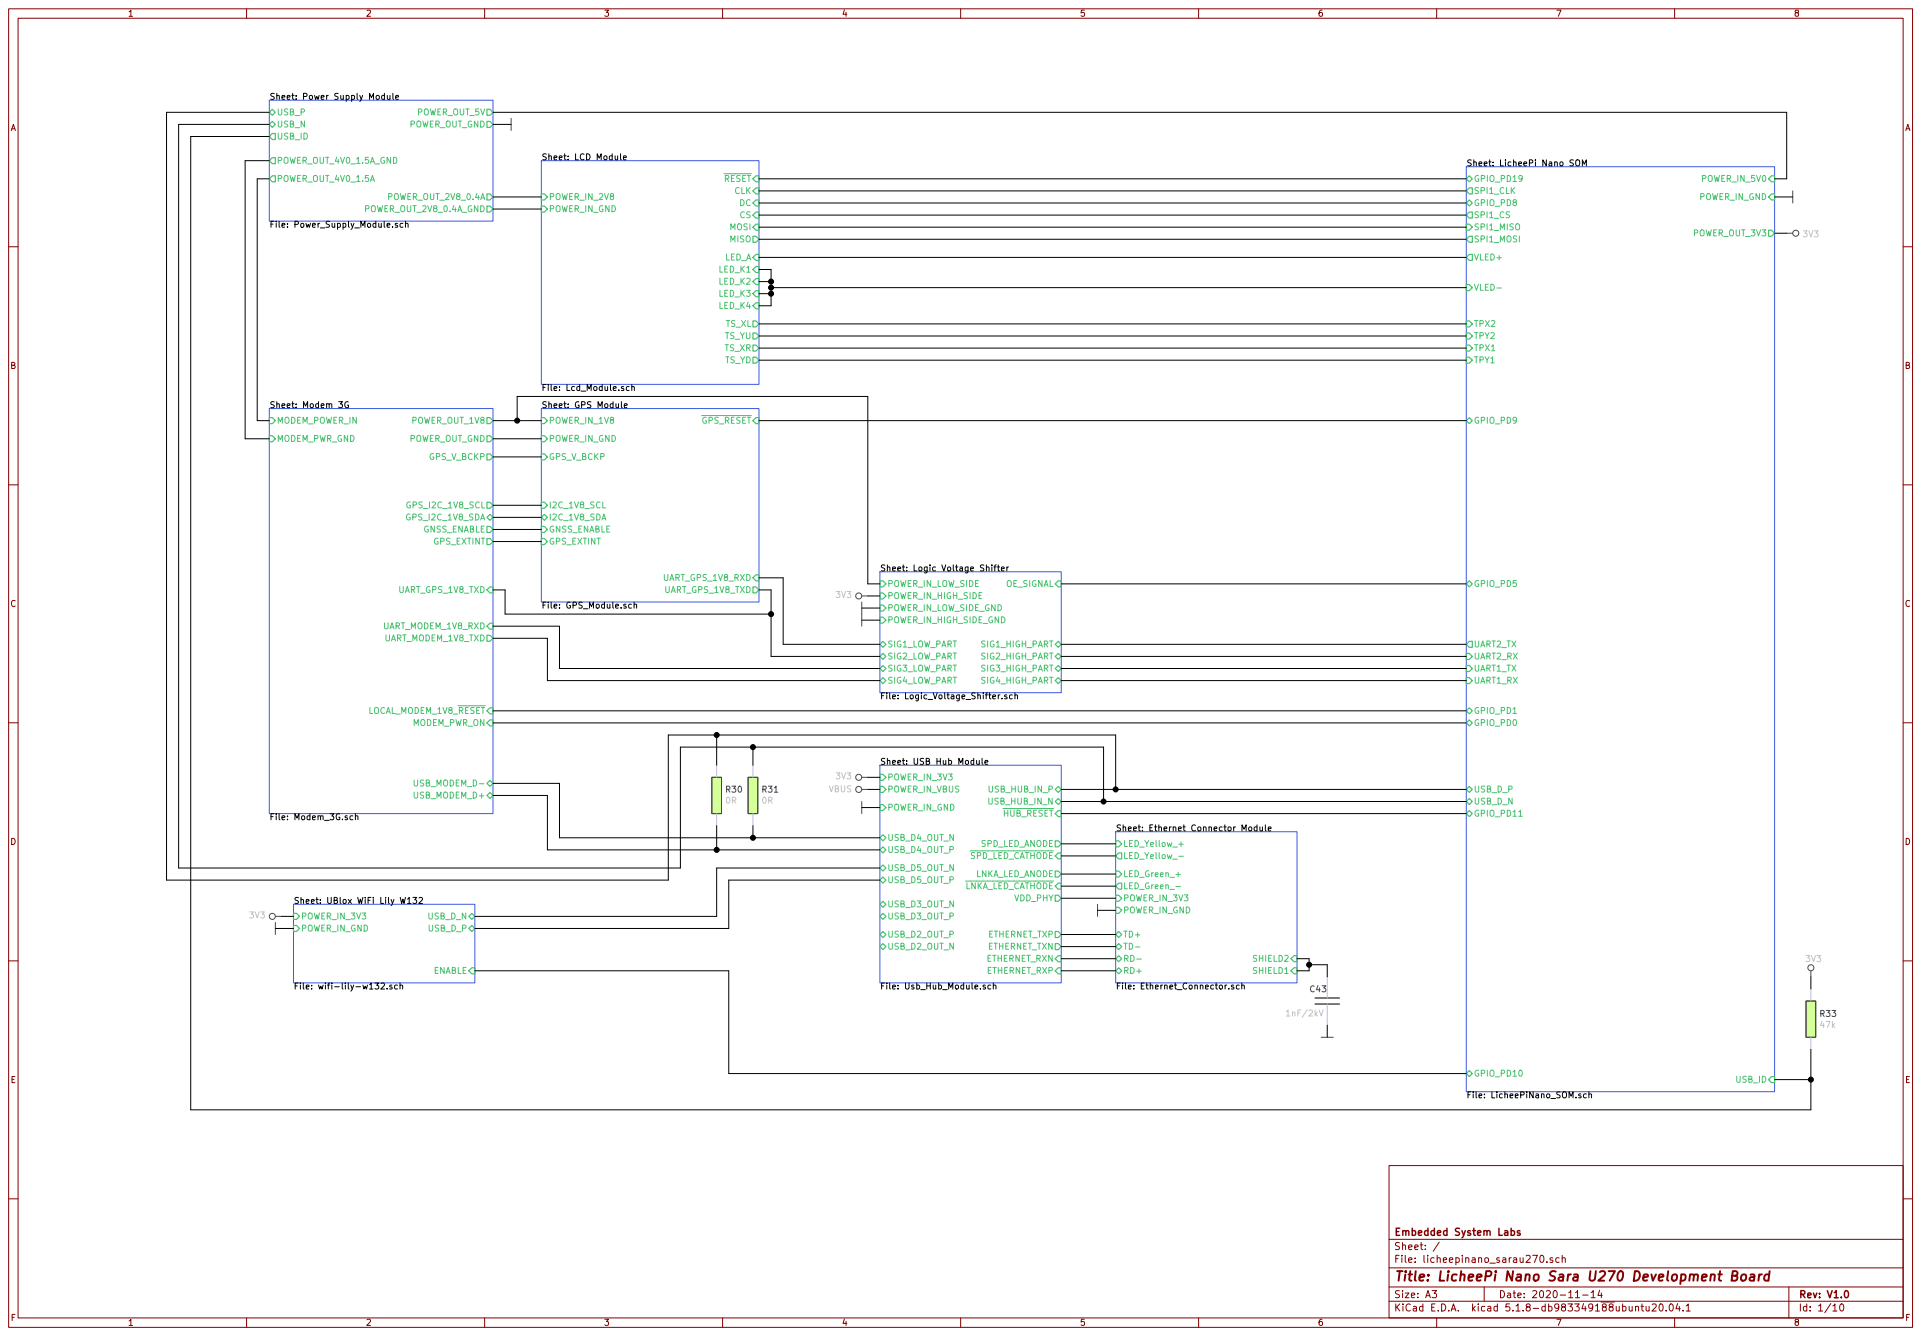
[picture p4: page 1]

POWER_OUT_GND
Sheet: LCD Module File: Lcd_Module.sch POWER_IN_2V8 POWER_IN_GND

Sheet: LicheePi Nano SOM

Sheet: USB Hub Module File: Usb_Hub_Module.sch USB_HUB_IN_P USB_HUB_IN_N
POWER_IN_3V3 POWER_IN_VBUS

Sheet: UBlox WiFi Lily W132
File: wifi-lily-w132.sch POWER_IN_3V3 POWER_IN_GND

File: licheepinano_sarau270.sch Sheet: / Embedded System Labs

Id: 1/10 Title: LicheePi Nano Sara U270 Development Board

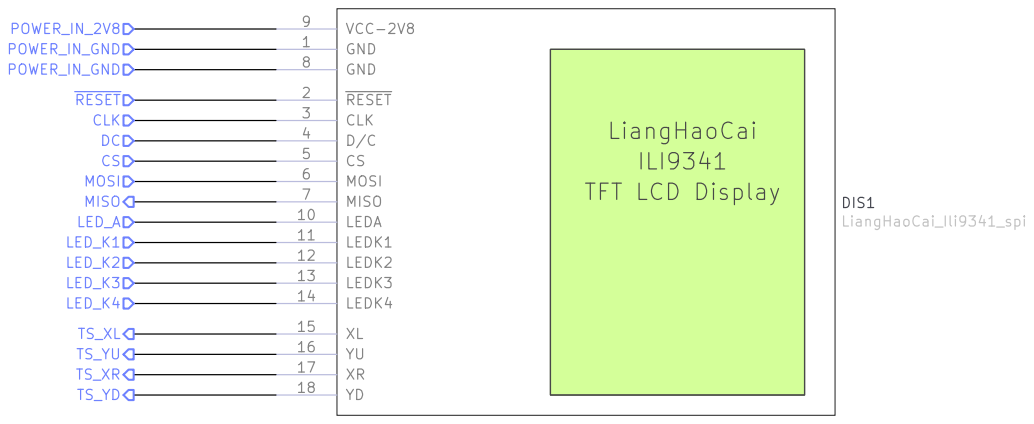
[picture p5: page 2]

File: Lcd_Module.sch Sheet: /LCD Module/ Embedded System Labs

Id: 2/10 Title: LCD Module

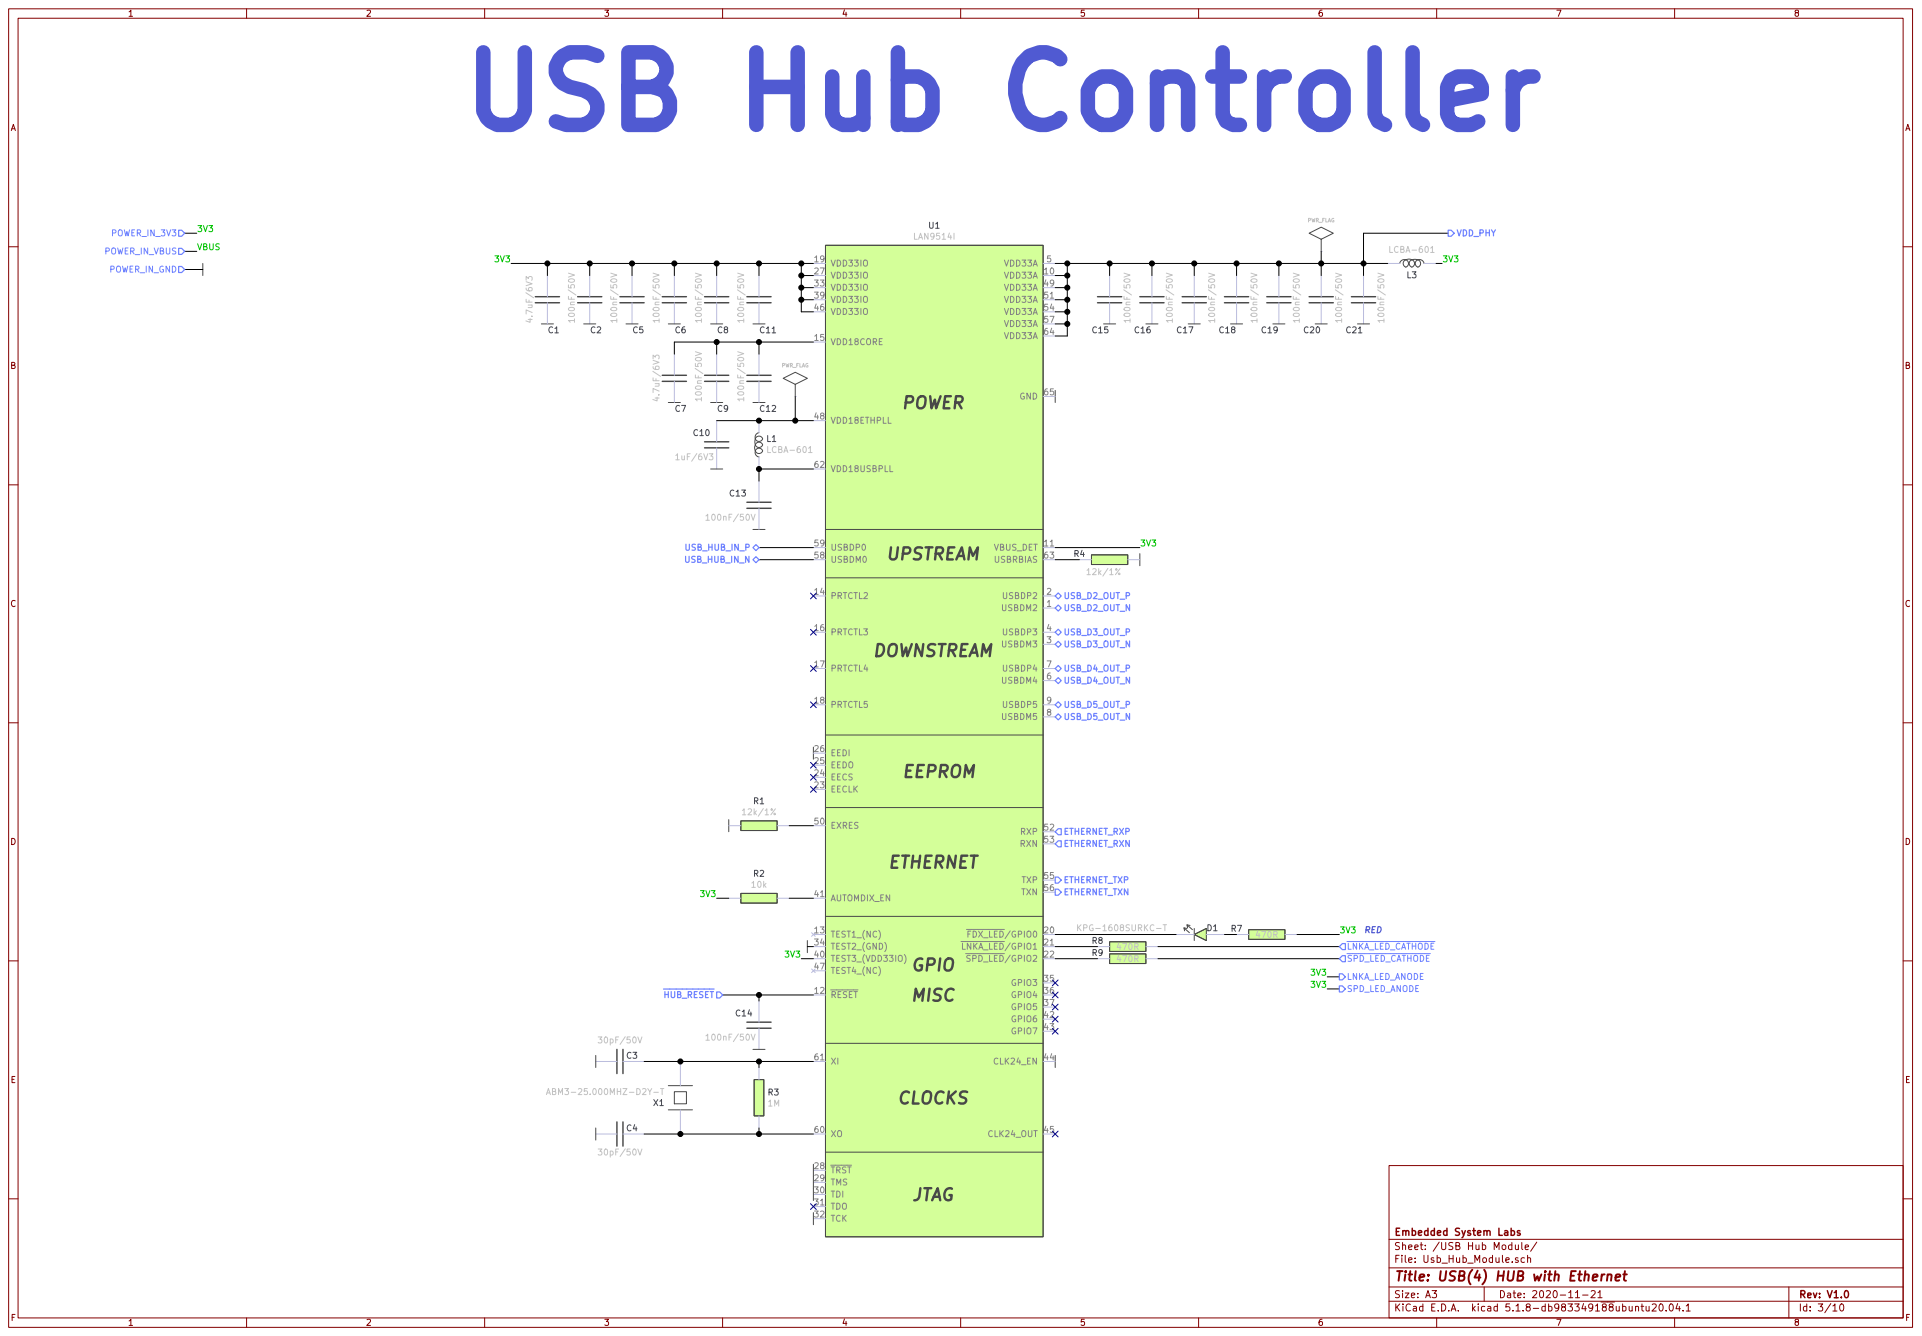
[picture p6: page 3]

File: Usb_Hub_Module.sch Sheet: /USB Hub Module/ Embedded System Labs

Id: 3/10 Title: USB(4) HUB with Ethernet

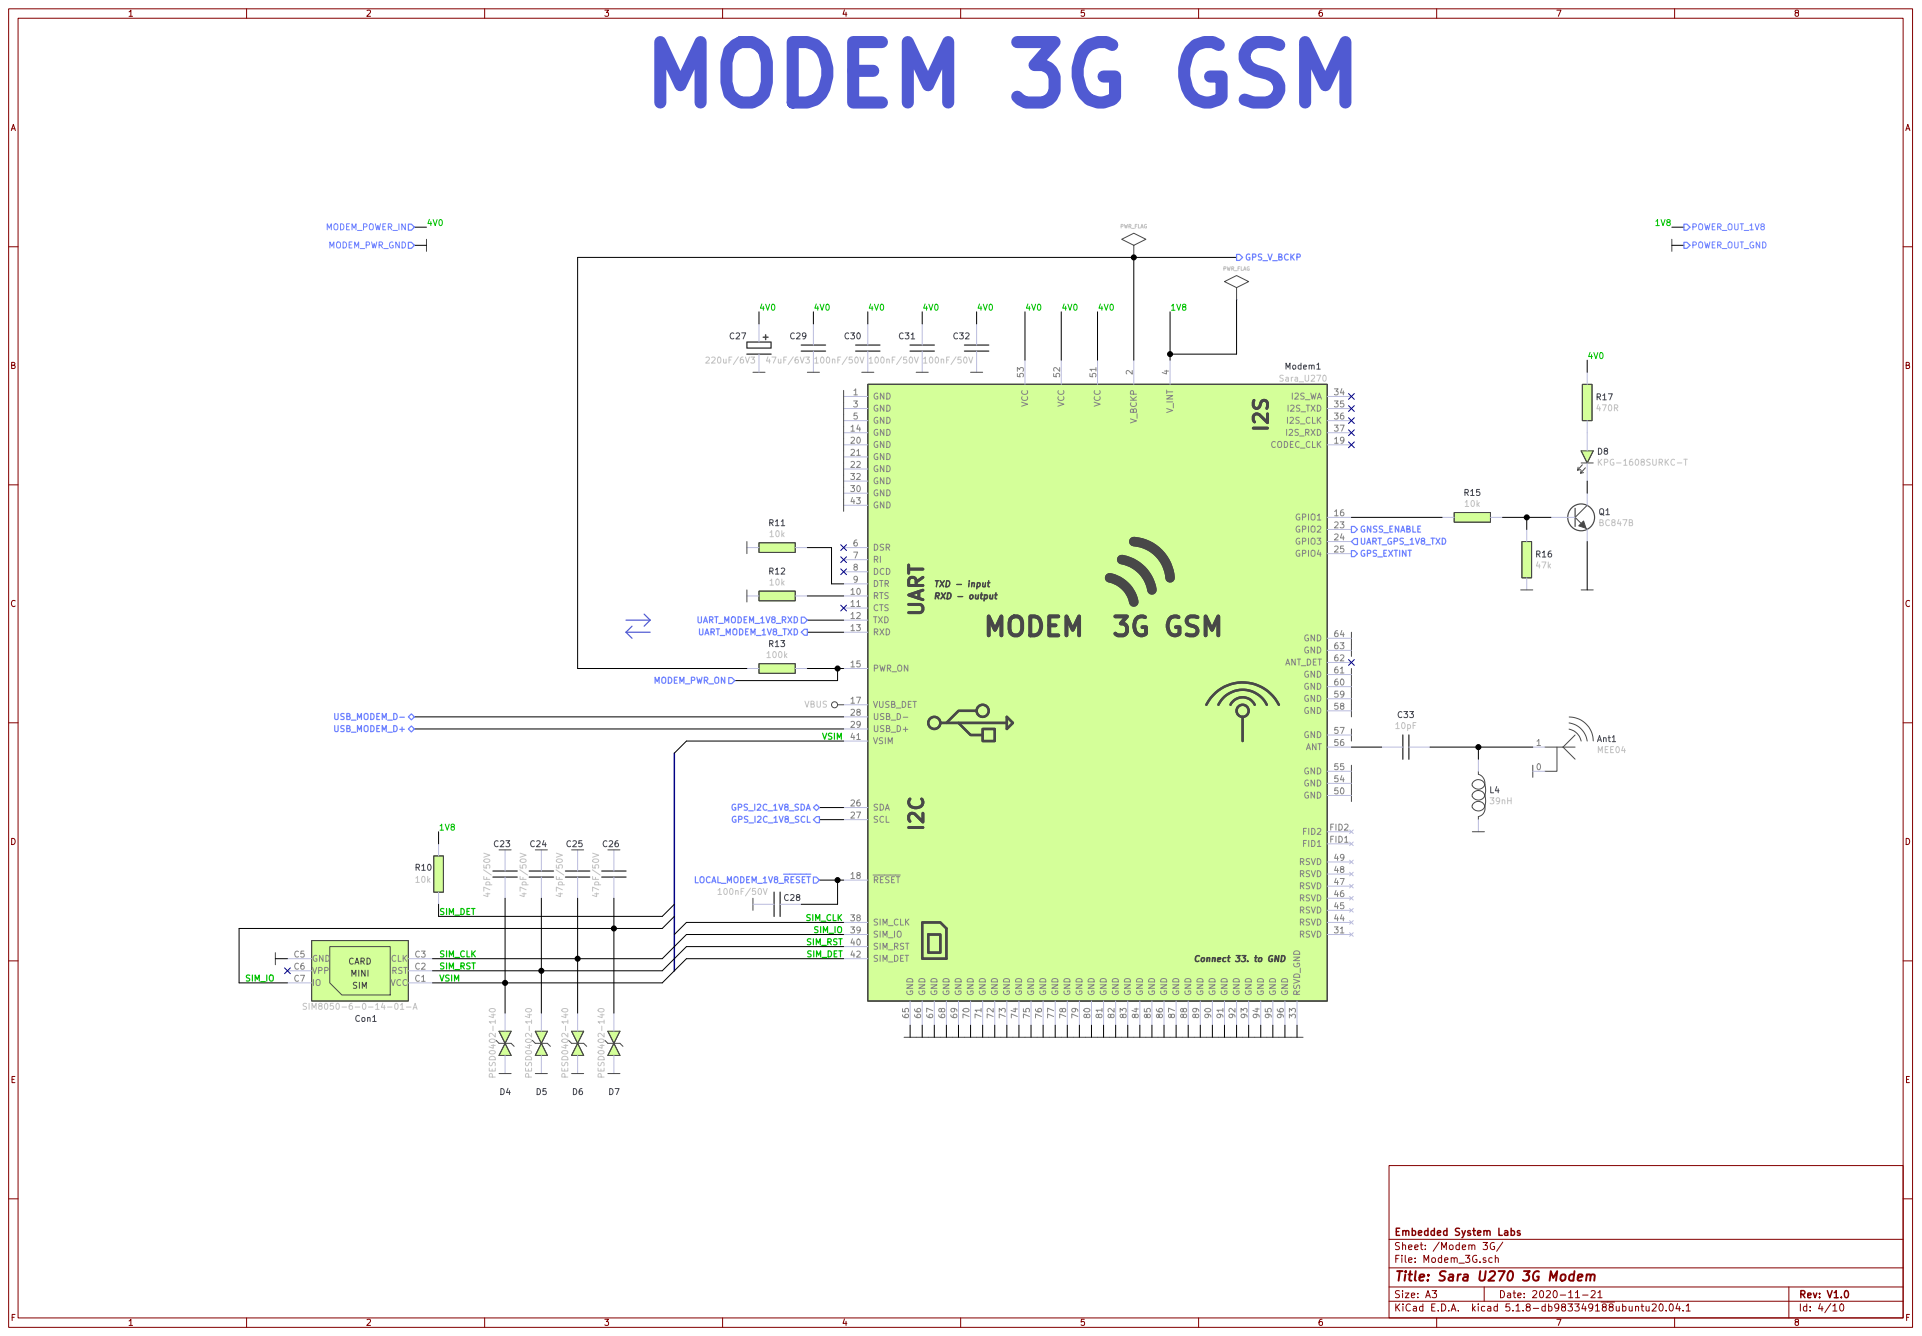
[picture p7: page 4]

4 SIM_RST 40 VSIM 41 SIM_DET 42 GND 43 RSVD 44 RSVD 45 RSVD 46 RSVD 47 RSVD 48 RSVD 49 GND 5 GND 50 VCC 51 VCC 52 VCC 53 GND 54 GND 55 ANT 56 GND 57 GND 58 GND 59 DSR 6 GND 60 GND 61 ANT_DET 62 GND 63 GND 64 GND 65 GND 66 GND 67 GND 68 GND 69 RI 7 GND 70 GND 71 GND 72 GND 73 GND 74 GND 75 GND 76 GND 77 GND 78 GND 79 DCD 8 GND 80 GND 81 GND 82 GND 83 GND 84 GND 85 GND 86 GND 87 GND 88 GND 89 DTR 9 GND 90 GND 91 GND 92 GND 93 GND 94 GND 95 GND 96 FID1 FID1 FID2 FID2 Modem1 Sara_U270 R17

2 GND 20 GND 21 GND 22 GPIO2 23 GPIO3 24 GPIO4 25 SDA 26 SCL 27 USB_D- 28 USB_D+ 29 GND 3 GND 30 RSVD 31 GND 32 RSVD_GND 33

Id: 4/10 Title: Sara U270 3G Modem

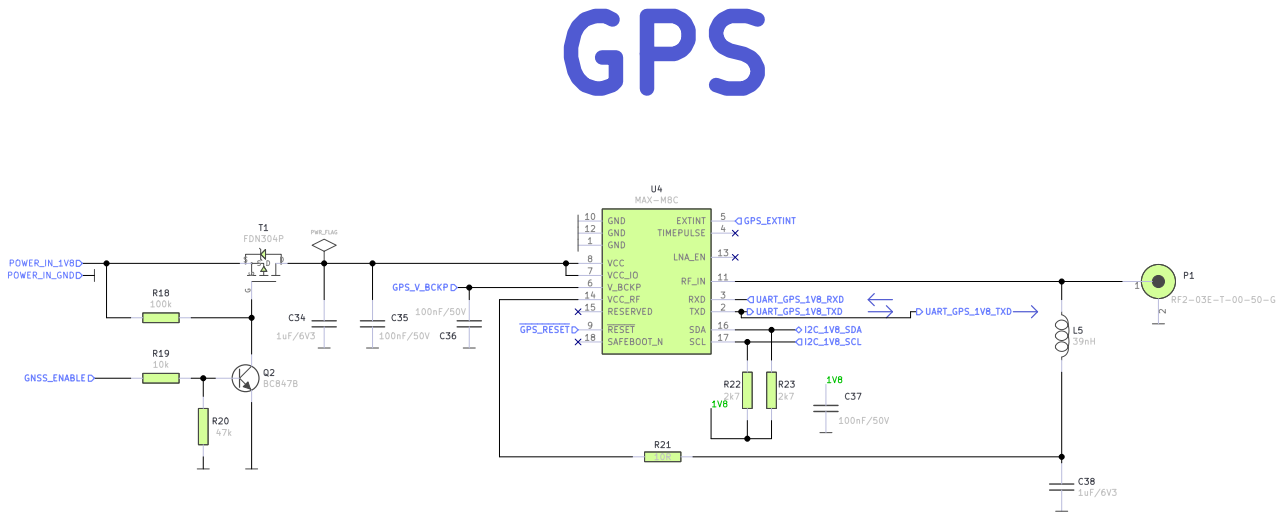
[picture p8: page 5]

File: GPS_Module.sch Sheet: /GPS Module/ Embedded System Labs

Id: 5/10 Title: GPS UBlox Max M8C

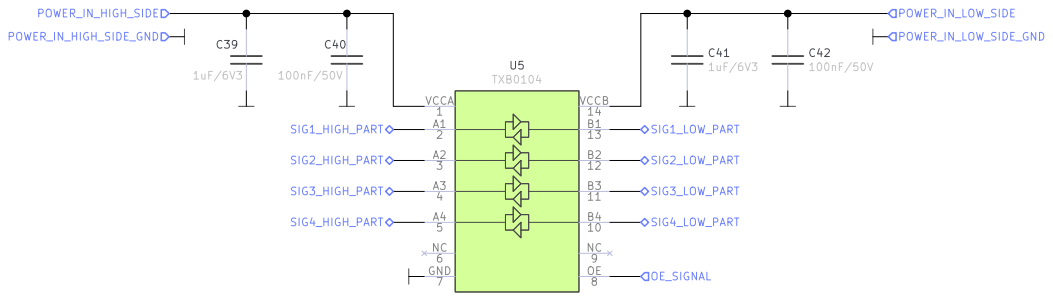
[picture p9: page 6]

Embedded System Labs
Sheet: /Logic Voltage Shifter/
File: Logic_Voltage_Shifter.sch
Id: 6/10 Title: Logic Level Shifter Module

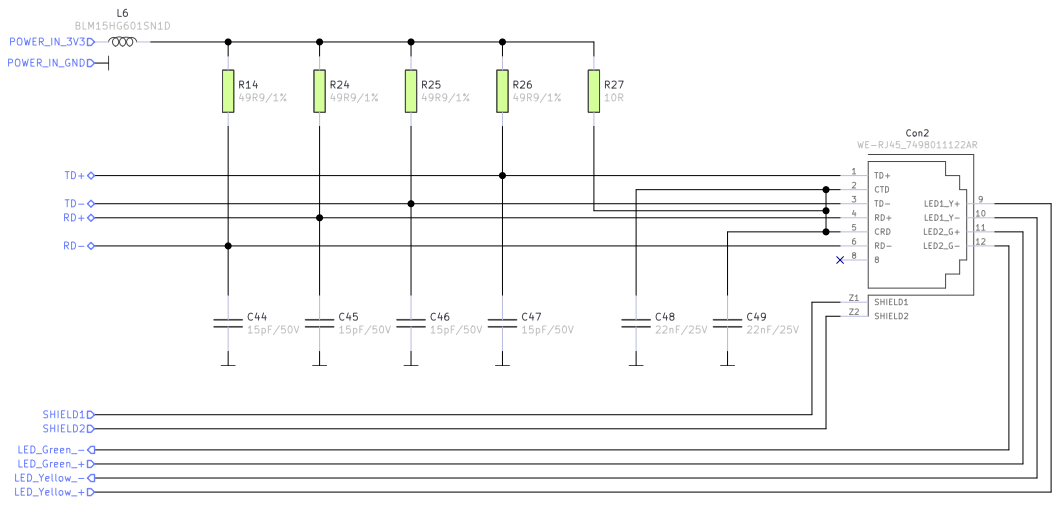
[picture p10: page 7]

L6 BLM15HG601SN1D
TD+ TD- RD+ RD- SHIELD1 SHIELD2 POWER_IN_3V3 POWER_IN_GND

File: Ethernet_Connector.sch Sheet: /Ethernet Connector Module/ Embedded System Labs

Id: 7/10 Title: Ethernet Connector Module

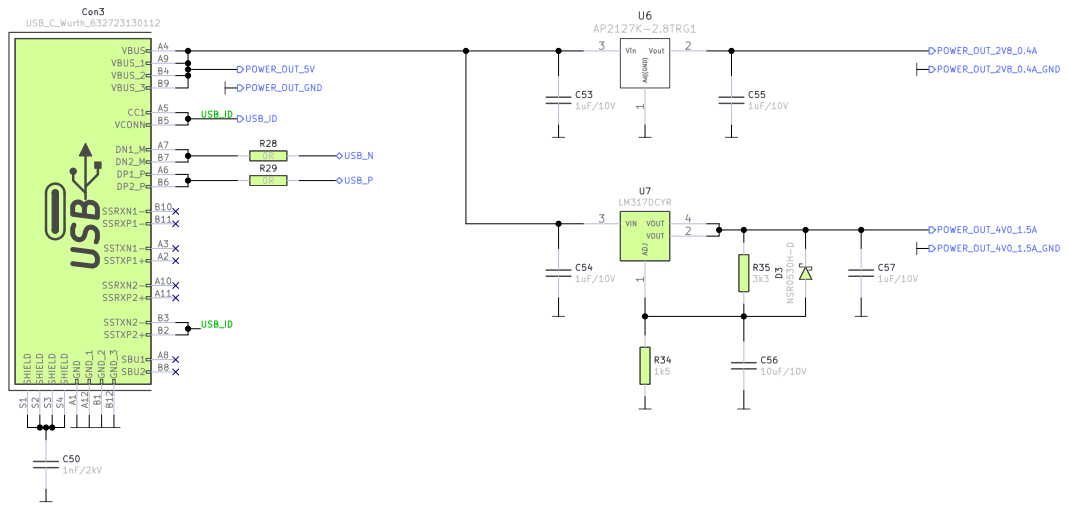
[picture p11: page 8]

Embedded System Labs
Sheet: /Power Supply Module/
File: Power_Supply_Module.sch
Id: 8/10 Title: Power Supply Module

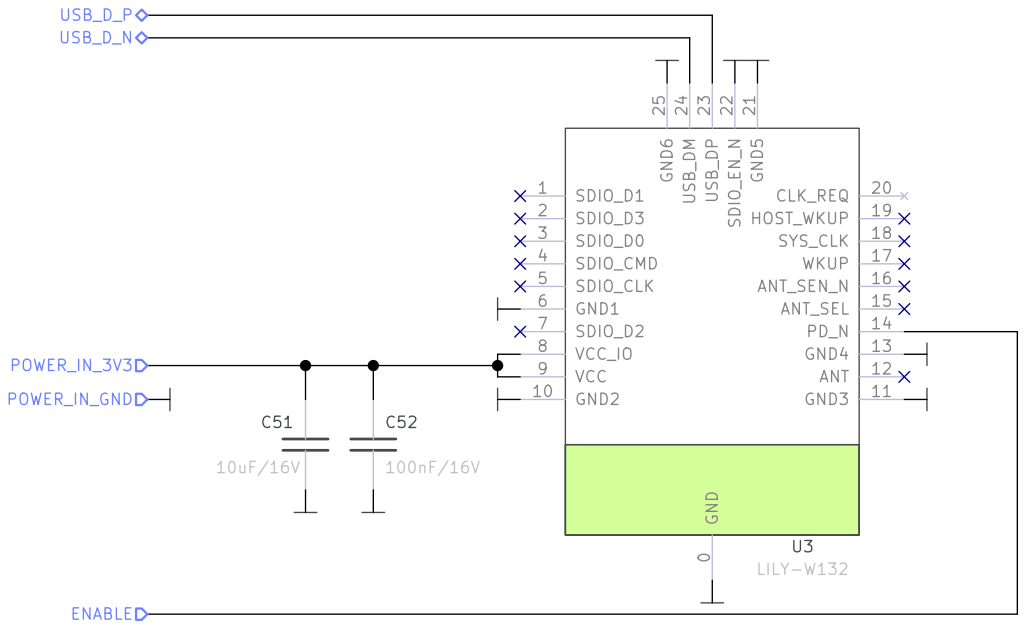
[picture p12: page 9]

Sheet: /UBlox WiFi Lily W132/ EMAR SJ GND

File: wifi-lily-w132.sch
Id: 9/10 Title: WiFi Module Lily-W132 uBlox

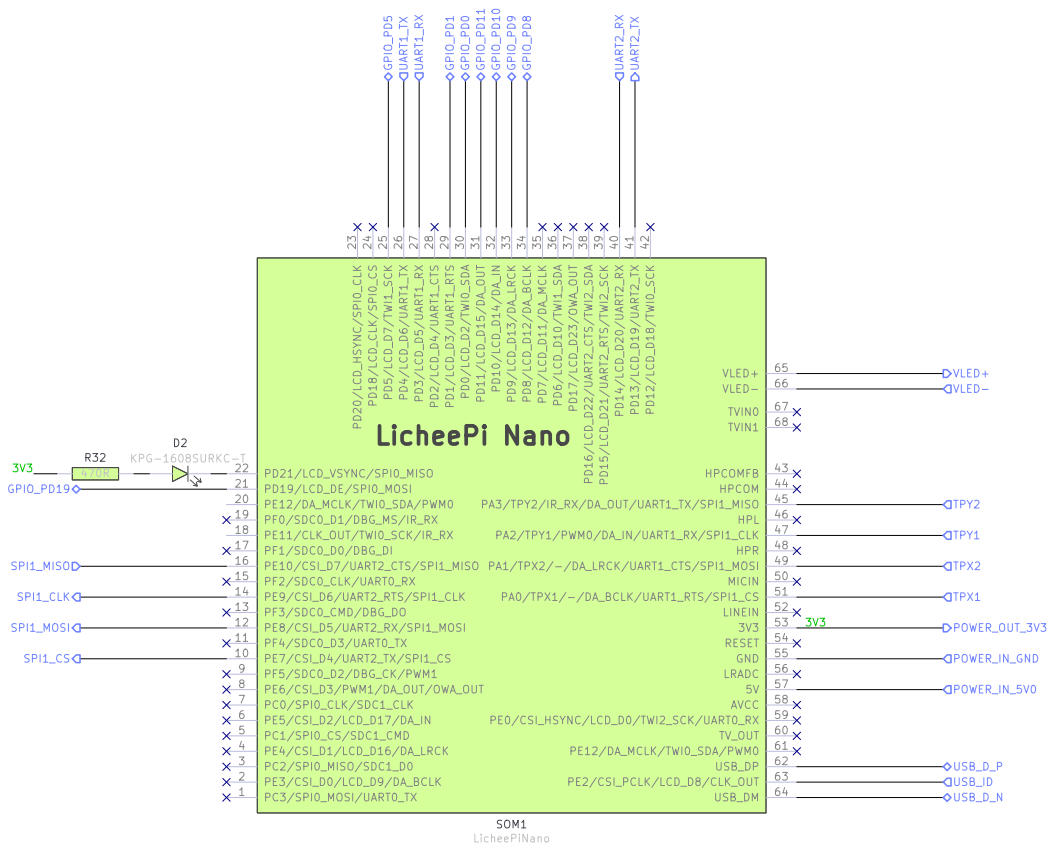
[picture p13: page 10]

File: LicheePiNano_SOM.sch Sheet: /LicheePi Nano SOM/ Embedded System Labs

Id: 10/10 Title: LicheePi Nano SOM

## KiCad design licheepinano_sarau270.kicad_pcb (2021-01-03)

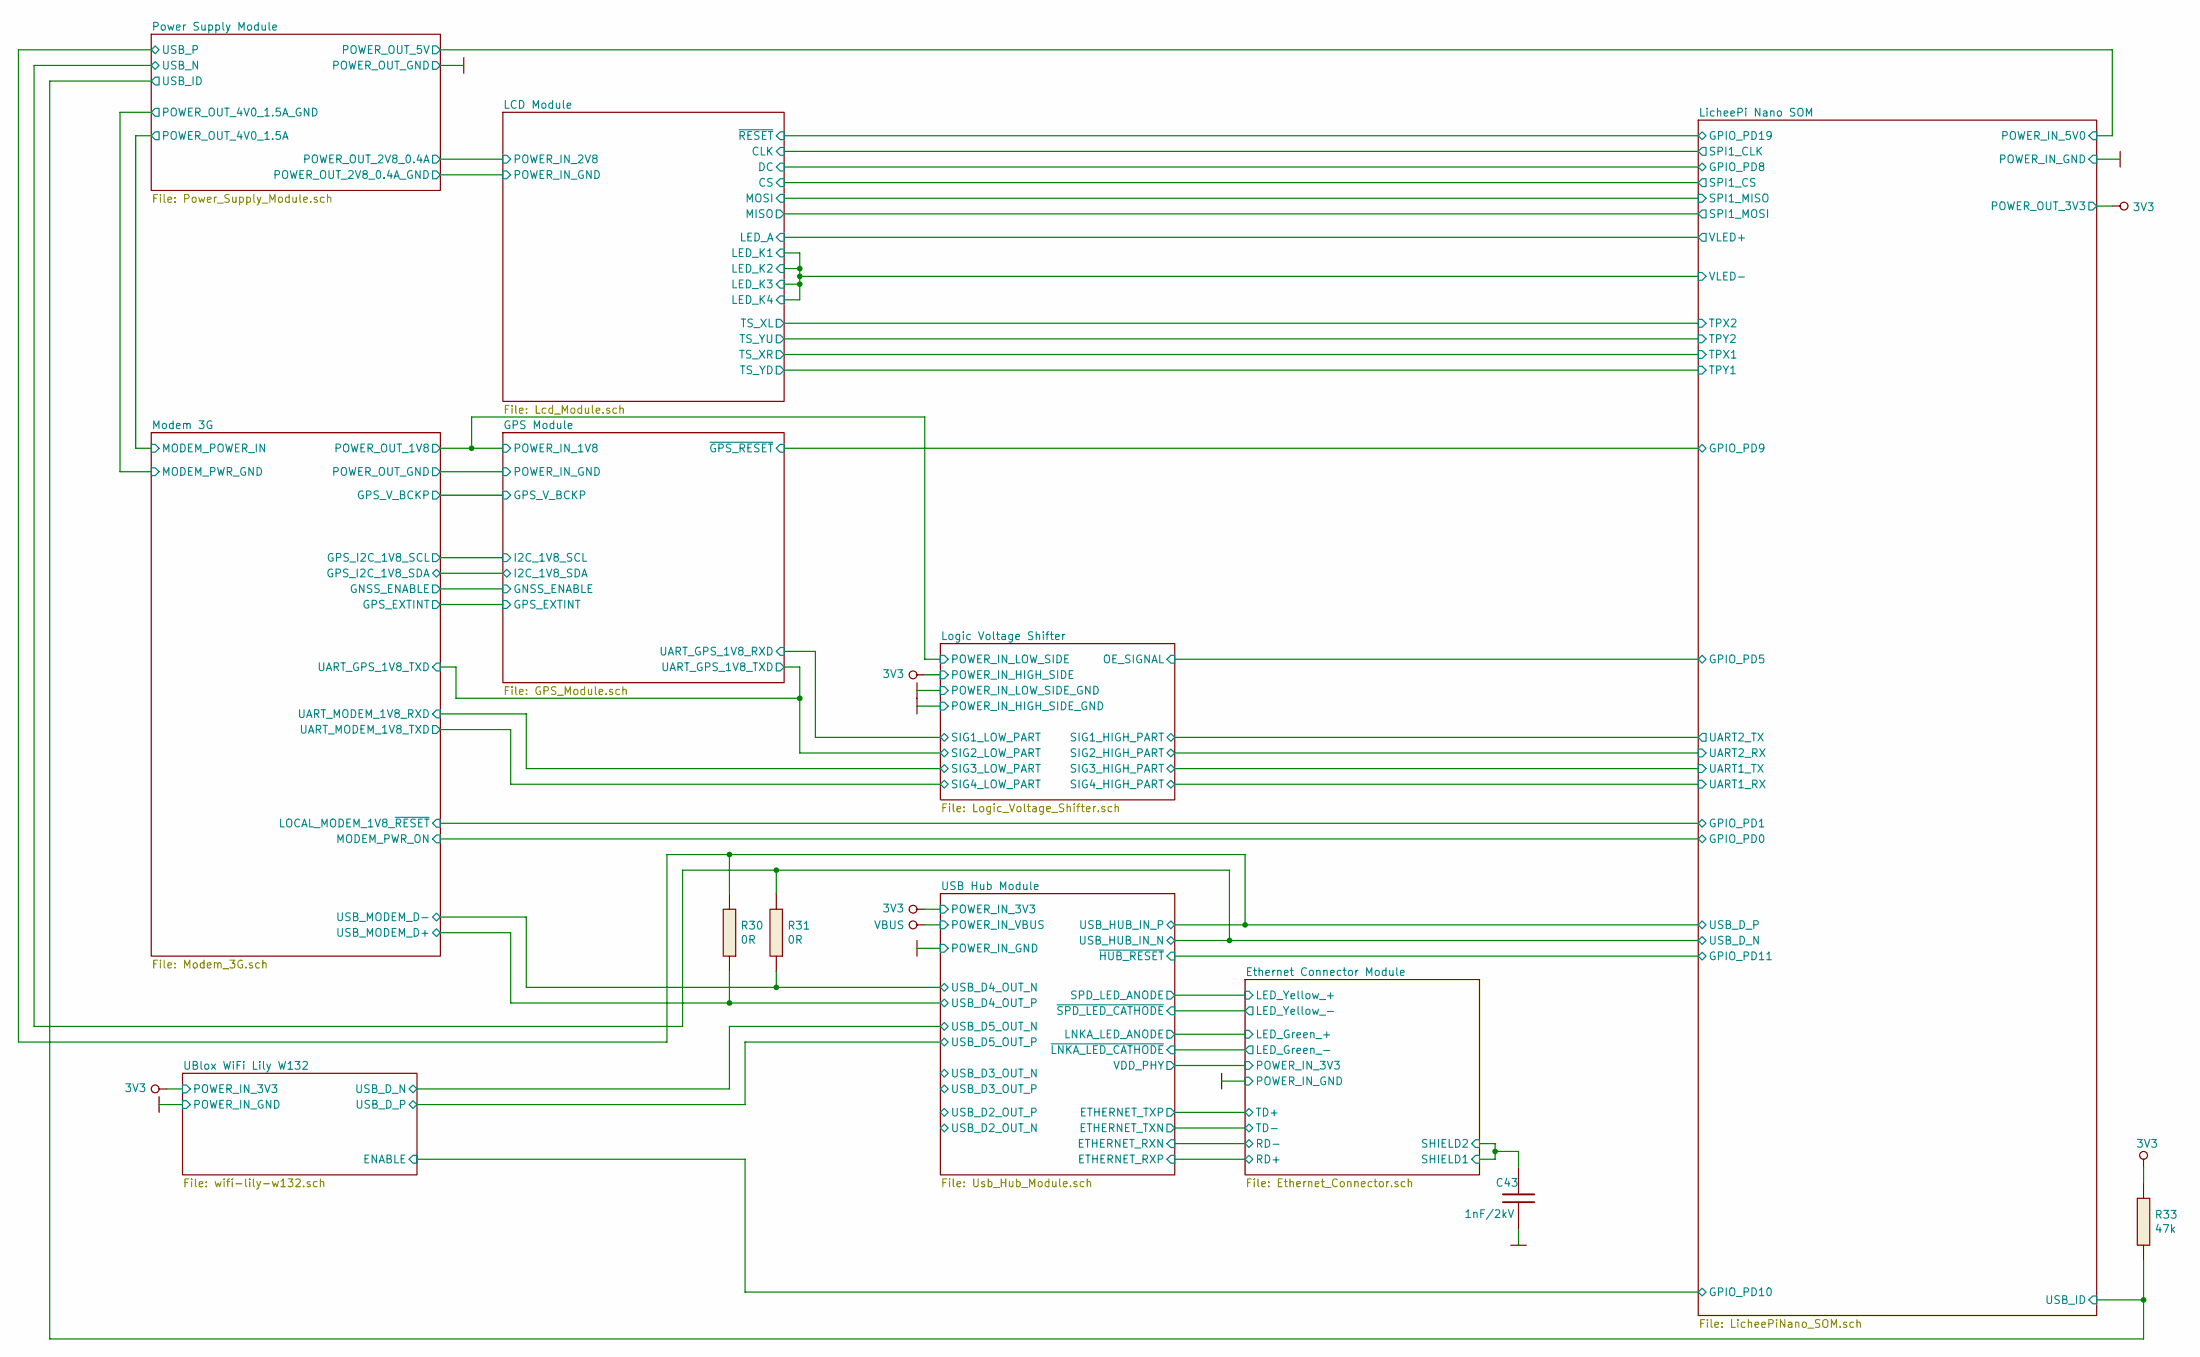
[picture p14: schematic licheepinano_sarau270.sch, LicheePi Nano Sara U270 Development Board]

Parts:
C43: 1nF/2kV; 1nF_2kV_1206; Manufacturer Part Number CC1206KKX7RDBB102
R30, R31: 0R; 0R_0402; Manufacturer Part Number CRCW04020000Z0ED; LCSC Part # (optional) C325378
R33: 47k; 47k_0402; Manufacturer Part Number CQ02WGF4702TCE

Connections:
3V3: R33.1; also elsewhere on the board
/Ethernet Connector Module/SHIELD1: C43.1; also elsewhere on the board
/LicheePi Nano SOM/USB_D_N: R31.2; also elsewhere on the board
/LicheePi Nano SOM/USB_D_P: R30.2; also elsewhere on the board
/LicheePi Nano SOM/USB_ID: R33.2; also elsewhere on the board
/USB Hub Module/USB_D4_OUT_N: R31.1; also elsewhere on the board
/USB Hub Module/USB_D4_OUT_P: R30.1; also elsewhere on the board
GND: C43.2; also elsewhere on the board

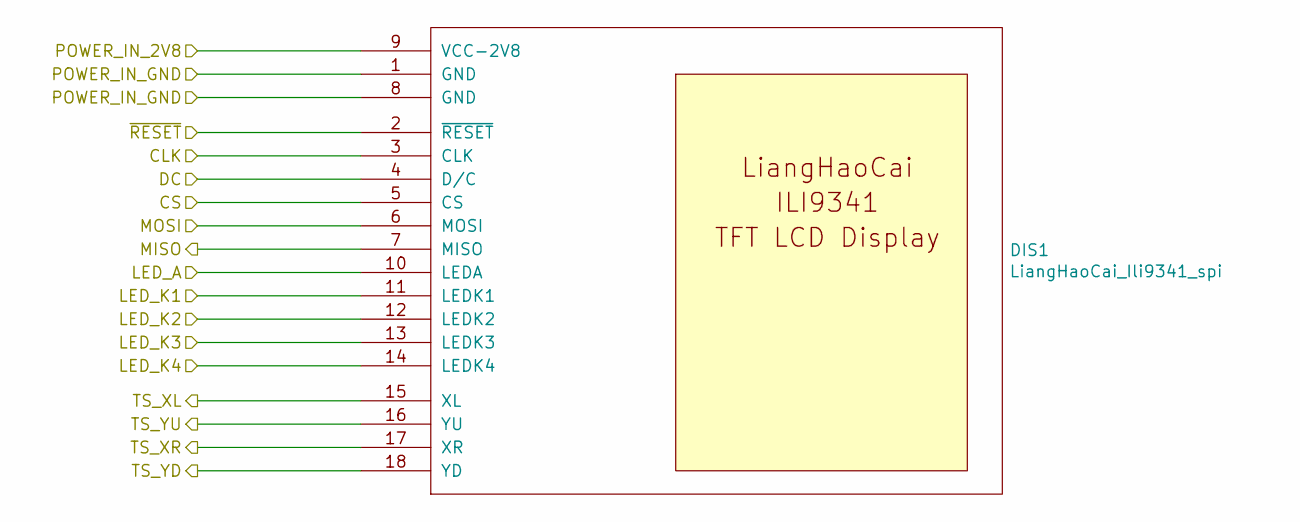
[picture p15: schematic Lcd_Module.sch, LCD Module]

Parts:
DIS1: LiangHaoCai_Ili9341_spi

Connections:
/LCD Module/CLK: DIS1.3 (CLK); also elsewhere on the board
/LCD Module/CS: DIS1.5 (CS); also elsewhere on the board
/LCD Module/DC: DIS1.4 (D/C); also elsewhere on the board
/LCD Module/LED_A: DIS1.10 (LEDA); also elsewhere on the board
/LCD Module/LED_K1: DIS1.11 (LEDK1), DIS1.12 (LEDK2), DIS1.13 (LEDK3), DIS1.14 (LEDK4); also elsewhere on the board
/LCD Module/MISO: DIS1.7 (MISO); also elsewhere on the board
/LCD Module/MOSI: DIS1.6 (MOSI); also elsewhere on the board
/LCD Module/POWER_IN_2V8: DIS1.9 (VCC-2V8); also elsewhere on the board
/LicheePi Nano SOM/GPIO_PD19: DIS1.2 (~RESET); also elsewhere on the board
/LicheePi Nano SOM/TPX1: DIS1.17 (XR); also elsewhere on the board
/LicheePi Nano SOM/TPX2: DIS1.15 (XL); also elsewhere on the board
/LicheePi Nano SOM/TPY1: DIS1.18 (YD); also elsewhere on the board
/LicheePi Nano SOM/TPY2: DIS1.16 (YU); also elsewhere on the board
GND: DIS1.1 (GND), DIS1.8 (GND); also elsewhere on the board

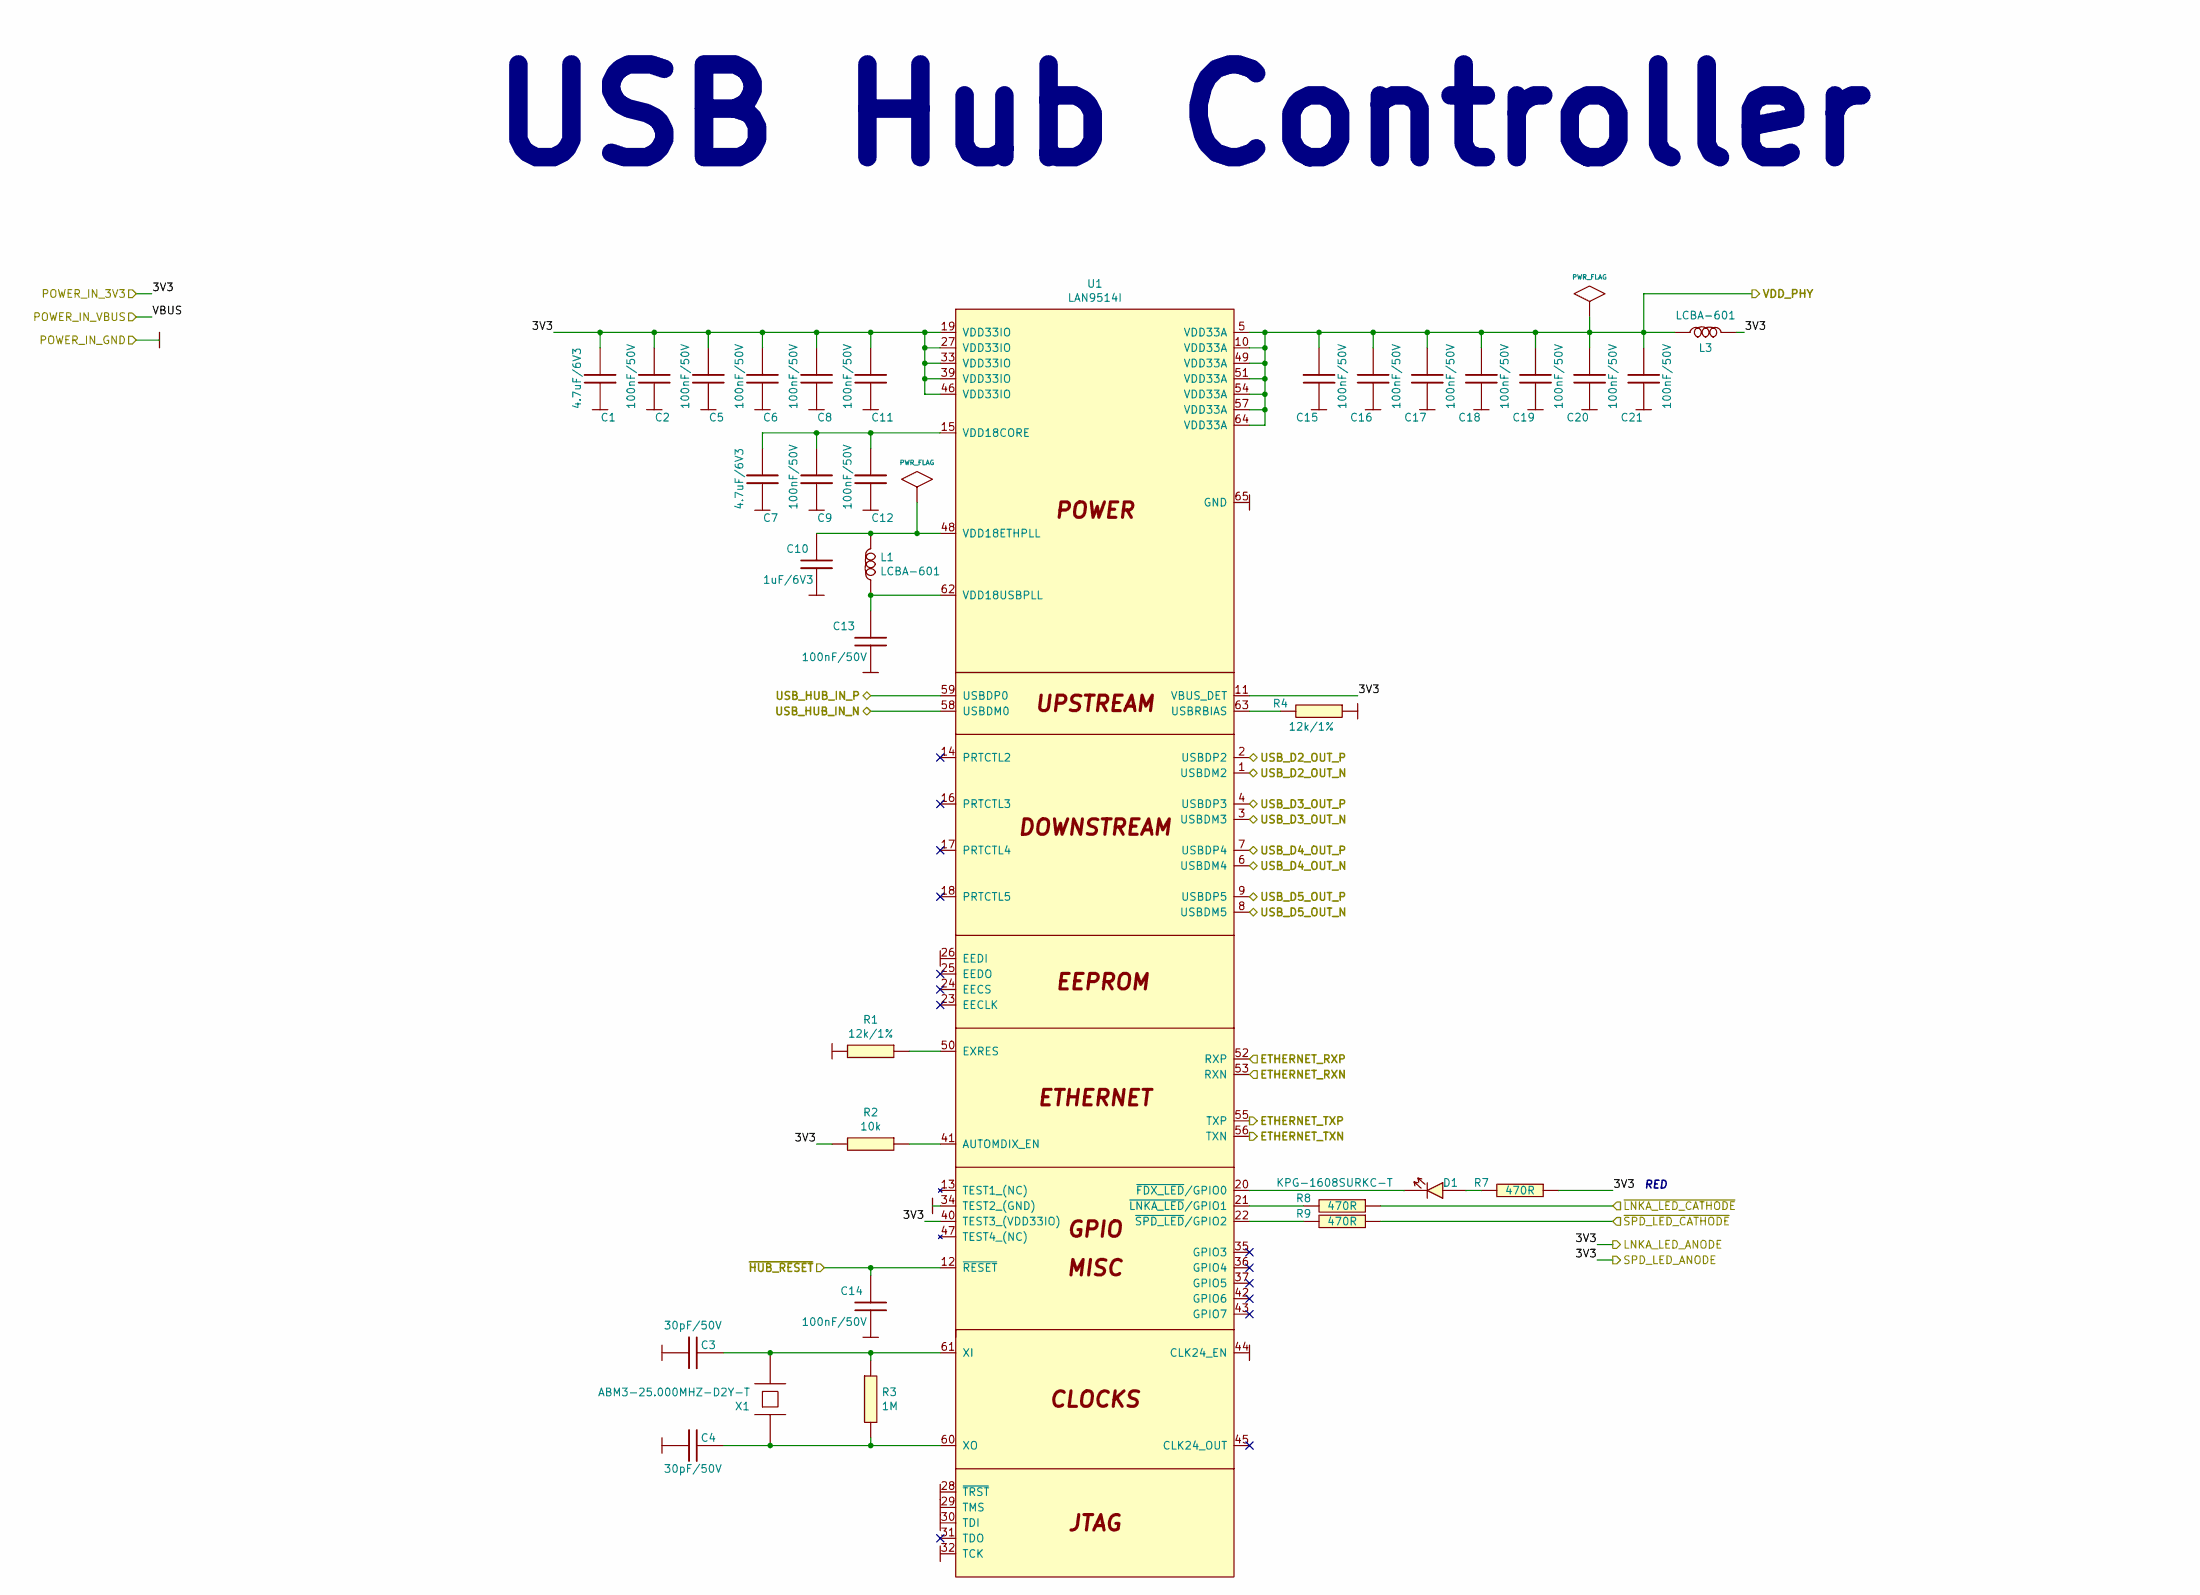
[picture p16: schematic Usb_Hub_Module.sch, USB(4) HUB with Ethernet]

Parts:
C1, C7: 4.7uF/6V3; 4_7uF_0603; Manufacturer Part Number CL10A475KQ8NNNC
C2, C5, C6, C8, C9, C11, C12, C13, C14, C15, C16, C17, C18, C19, C20, C21: 100nF/50V; 100nF_0402; Manufacturer Part Number CL05B104KO5NNNC
C3, C4: 30pF/50V; 30pF_0402; Manufacturer Part Number C0402C300J5GACTU
C10: 1uF/6V3; 1uF_0603; Manufacturer Part Number CL10B105KO8NNNC
D1: KPG-1608SURKC-T; LED_KPG-1608SURKC-T; Manufacturer Part Number KPG-1608SURKC-T
L1, L3: LCBA-601; Manufacturer Part Number LCBA-601
R1: 12k/1%; 12k4_0402; Manufacturer Part Number RC0402FR-0712K4L
R2: 10k; 10k_0402; Manufacturer Part Number 0402WGF1002TCE
R3: 1M; 1M_0402; Manufacturer Part Number 0402WGF1004TCE
R4: 12k/1%; 12k_0402; Manufacturer Part Number CRGCQ0402F12K
R7, R8, R9: 470R; 470R_0402; Manufacturer Part Number 0402WGF4700TCE
U1: LAN9514I; Manufacturer Part Number LAN9514I-JZX
X1: ABM3-25.000MHZ-D2Y-T; Manufacturer Part Number ABM3-25.000MHZ-D2Y-T

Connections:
3V3: C1.1, C2.1, C5.1, C6.1, C8.1, C11.1, L3.2, R2.2, R7.1, U1.11 (VBUS_DET), U1.19 (VDD33IO), U1.27 (VDD33IO), U1.33 (VDD33IO), U1.39 (VDD33IO), U1.40 (TEST3_(VDD33IO)), U1.46 (VDD33IO); also elsewhere on the board
/Ethernet Connector Module/LED_Green_-: R8.1; also elsewhere on the board
/Ethernet Connector Module/LED_Yellow_-: R9.1; also elsewhere on the board
/Ethernet Connector Module/POWER_IN_3V3: C15.1, C16.1, C17.1, C18.1, C19.1, C20.1, C21.1, L3.1, U1.5 (VDD33A), U1.10 (VDD33A), U1.49 (VDD33A), U1.51 (VDD33A), U1.54 (VDD33A), U1.57 (VDD33A), U1.64 (VDD33A); also elsewhere on the board
/LicheePi Nano SOM/GPIO_PD11: C14.1, U1.12 (~RESET); also elsewhere on the board
/LicheePi Nano SOM/USB_D_N: U1.58 (USBDM0); also elsewhere on the board
/LicheePi Nano SOM/USB_D_P: U1.59 (USBDP0); also elsewhere on the board
/USB Hub Module/ETHERNET_RXN: U1.53 (RXN); also elsewhere on the board
/USB Hub Module/ETHERNET_RXP: U1.52 (RXP); also elsewhere on the board
/USB Hub Module/ETHERNET_TXN: U1.56 (TXN); also elsewhere on the board
/USB Hub Module/ETHERNET_TXP: U1.55 (TXP); also elsewhere on the board
/USB Hub Module/USB_D4_OUT_N: U1.6 (USBDM4); also elsewhere on the board
/USB Hub Module/USB_D4_OUT_P: U1.7 (USBDP4); also elsewhere on the board
/USB Hub Module/USB_D5_OUT_N: U1.8 (USBDM5); also elsewhere on the board
/USB Hub Module/USB_D5_OUT_P: U1.9 (USBDP5); also elsewhere on the board
GND: C1.2, C2.2, C3.2, C4.1, C5.2, C6.2, C7.2, C8.2, C9.2, C10.2, C11.2, C12.2, C13.2, C14.2, C15.2, C16.2, C17.2, C18.2, C19.2, C20.2, C21.2, R1.2, R4.1, U1.26 (EEDI), U1.28 (~TRST), U1.29 (TMS), U1.30 (TDI), U1.32 (TCK), U1.34 (TEST2_(GND)), U1.44 (CLK24_EN), U1.65 (GND); also elsewhere on the board
unnamed: C3.1, R3.1, U1.61 (XI), X1.2
unnamed: C4.2, R3.2, U1.60 (XO), X1.1
unnamed: C10.1, L1.2, U1.48 (VDD18ETHPLL)
unnamed: C7.1, C9.1, C12.1, U1.15 (VDD18CORE), U1.38 (VDD18CORE)
unnamed: C13.1, L1.1, U1.62 (VDD18USBPLL)
unnamed: D1.1 (A), R7.2
unnamed: D1.2 (K), U1.20 (~FDX_LED~/GPIO0)
unnamed: R1.1, U1.50 (EXRES)
unnamed: R2.1, U1.41 (AUTOMDIX_EN)
unnamed: R4.2, U1.63 (USBRBIAS)
unnamed: R8.2, U1.21 (~LNKA_LED~/GPIO1)
unnamed: R9.2, U1.22 (~SPD_LED~/GPIO2)

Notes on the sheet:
USB Hub Controller
RED

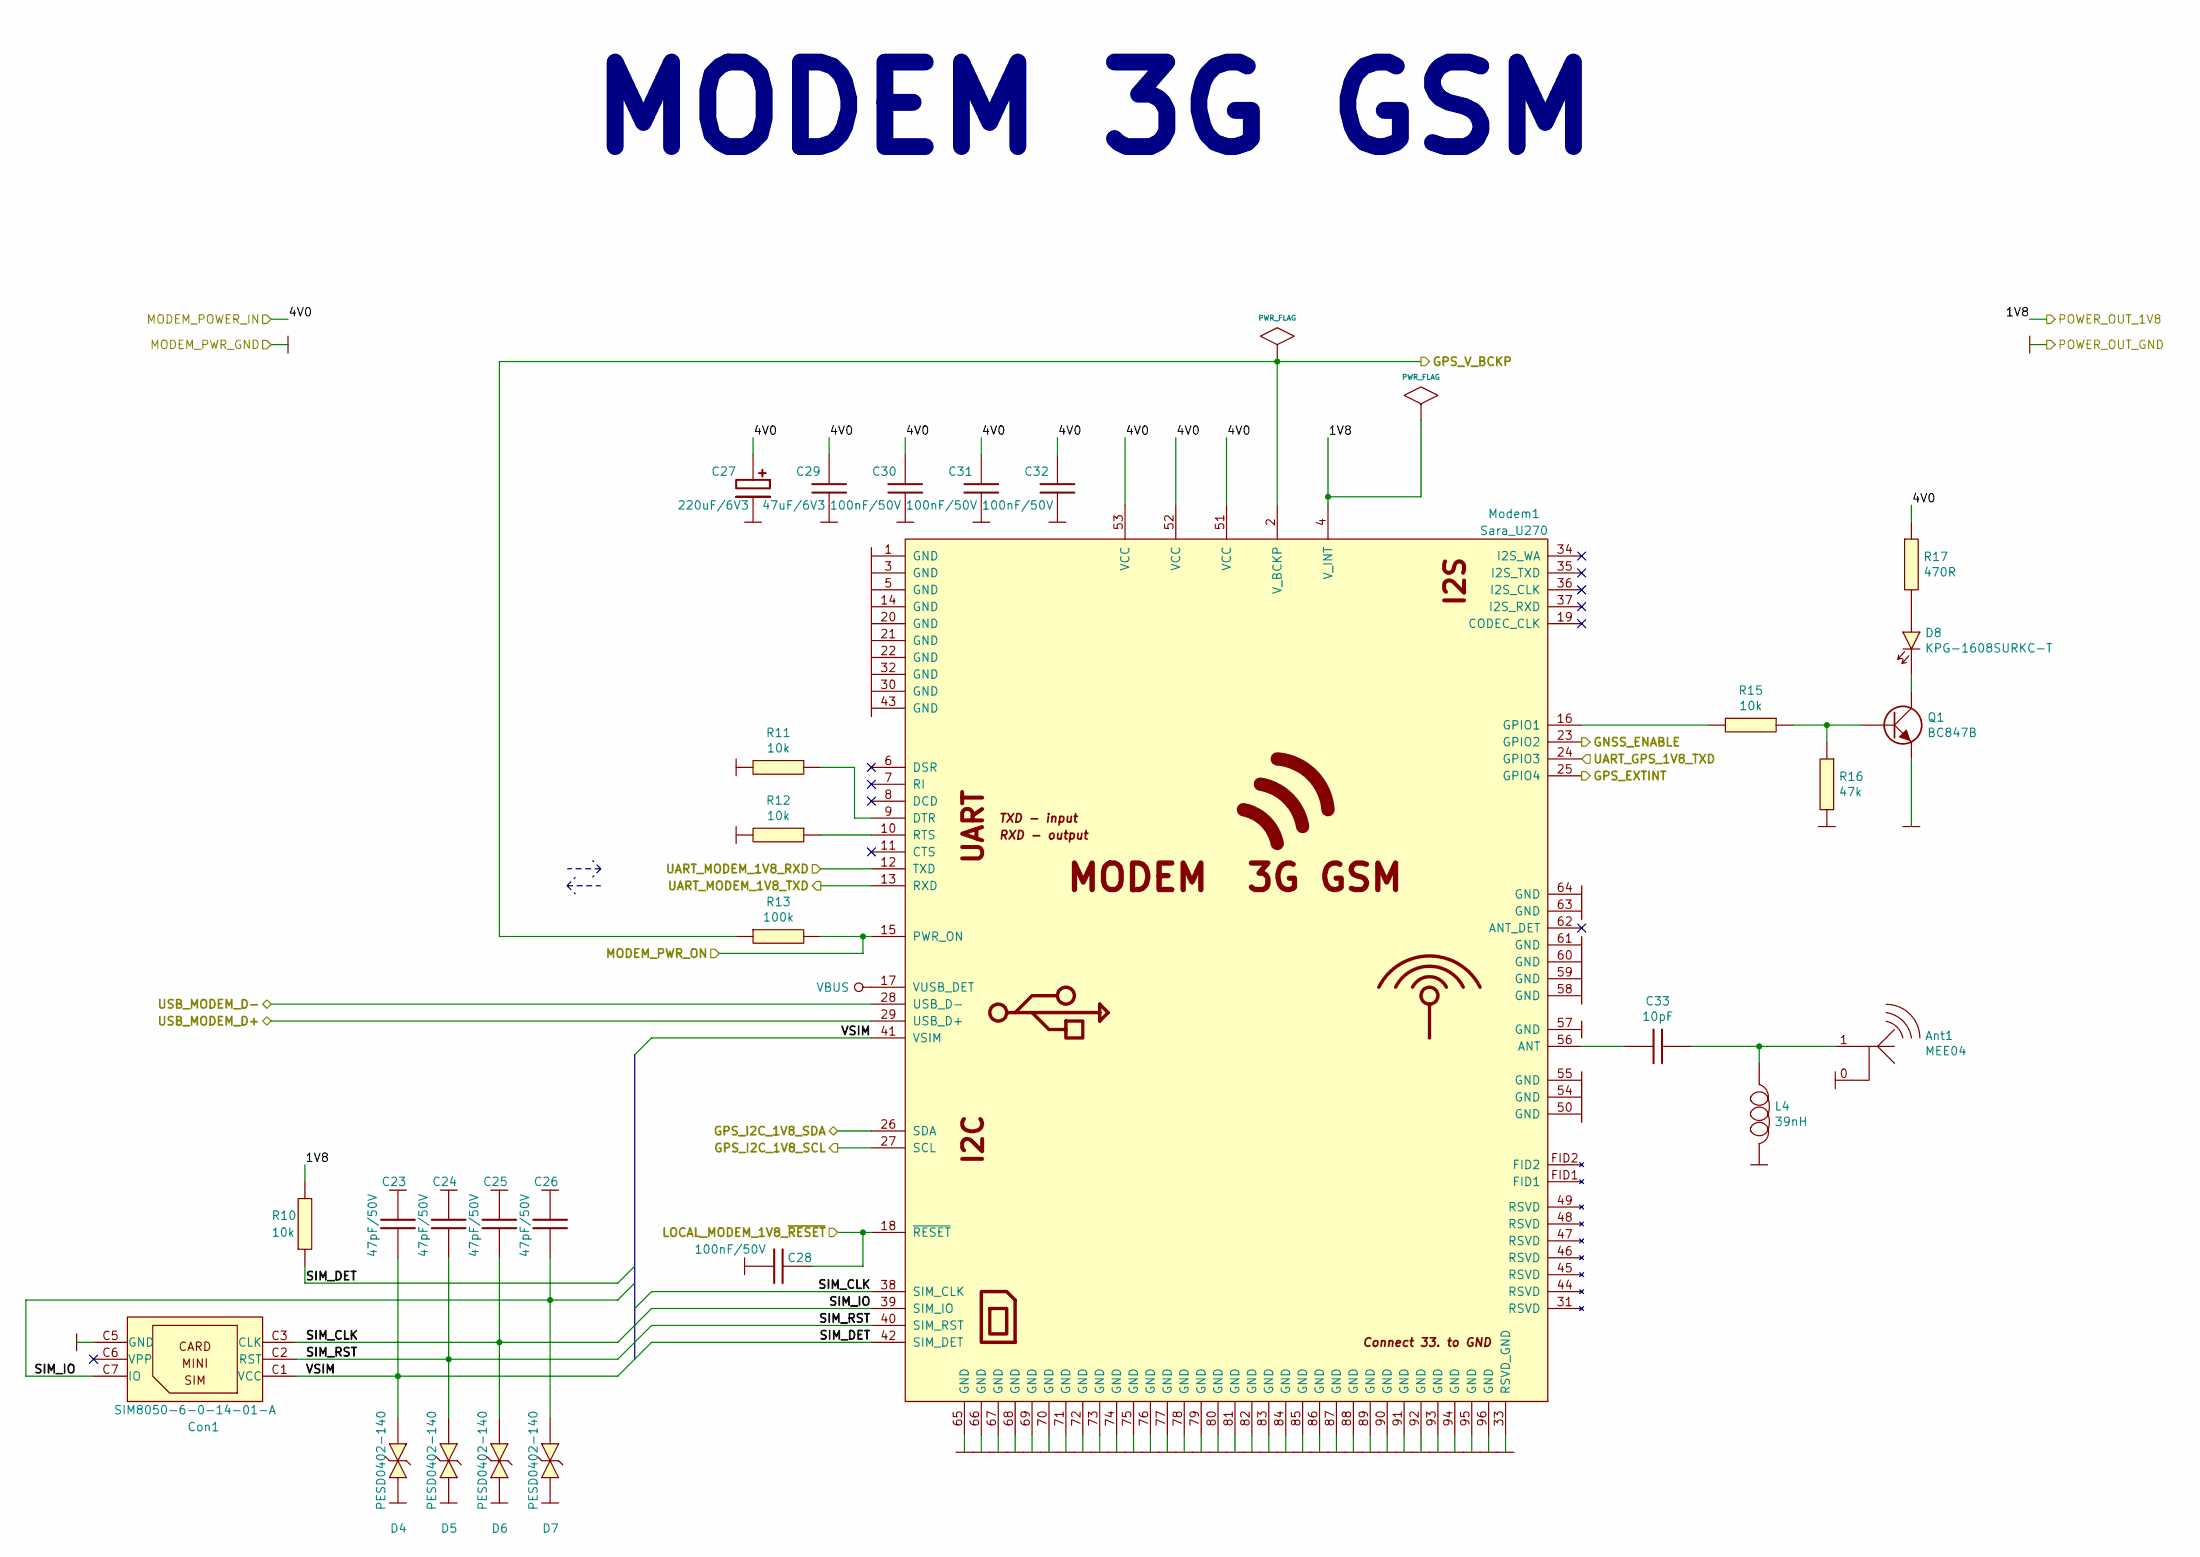
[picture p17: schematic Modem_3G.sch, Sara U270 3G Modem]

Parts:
Ant1: MEE04
C23, C24, C25, C26: 47pF/50V; 47pF_0402; Manufacturer Part Number 0402N470J500CT
C27: 220uF/6V3; 220uF_6_3V_Polymer_Horizontal_fi8_len8mm; Manufacturer Part Number 870025174002
C28, C30, C31, C32: 100nF/50V; 100nF_0603; Manufacturer Part Number CL10B104JB8NNNC
C29: 47uF/6V3; 47uF_1206; Manufacturer Part Number C3216X5R0J476M160AC
C33: 10pF; 10pF_0603; Manufacturer Part Number CL10C100JB8NNNC
Con1: SIM8050-6-0-14-01-A; Manufacturer Part Number SIM8050-6-0-14-01-A.
D4, D5, D6, D7: PESD0402-140; Manufacturer Part Number PESD0402-140
D8: KPG-1608SURKC-T; LED_KPG-1608SURKC-T; Manufacturer Part Number KPG-1608SURKC-T
L4: 39nH; 39nH_0603; Manufacturer Part Number HK160839NH-T
Modem1: Sara_U270
Q1: BC847B; BC847B_SOT23; Manufacturer Part Number BC847BE6327
R10, R11, R12, R15: 10k; 10k_0402; Manufacturer Part Number 0402WGF1002TCE
R13: 100k; 100k_0402; Manufacturer Part Number RC0402FR-07100K
R16: 47k; 47k_0402; Manufacturer Part Number CQ02WGF4702TCE
R17: 470R; 470R_0402; Manufacturer Part Number 0402WGF4700TCE

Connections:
/GPS Module/GNSS_ENABLE: Modem1.23 (GPIO2); also elsewhere on the board
/GPS Module/GPS_EXTINT: Modem1.25 (GPIO4); also elsewhere on the board
/GPS Module/GPS_V_BCKP: Modem1.2 (V_BCKP), R13.1; also elsewhere on the board
/GPS Module/POWER_IN_1V8: Modem1.4 (V_INT), R10.2; also elsewhere on the board
/LicheePi Nano SOM/GPIO_PD0: Modem1.15 (PWR_ON), R13.2; also elsewhere on the board
/LicheePi Nano SOM/GPIO_PD1: C28.1, Modem1.18 (~RESET); also elsewhere on the board
/Logic Voltage Shifter/SIG2_LOW_PART: Modem1.24 (GPIO3); also elsewhere on the board
/Logic Voltage Shifter/SIG3_LOW_PART: Modem1.12 (TXD); also elsewhere on the board
/Logic Voltage Shifter/SIG4_LOW_PART: Modem1.13 (RXD); also elsewhere on the board
/Modem 3G/GPS_I2C_1V8_SCL: Modem1.27 (SCL); also elsewhere on the board
/Modem 3G/GPS_I2C_1V8_SDA: Modem1.26 (SDA); also elsewhere on the board
/Modem 3G/MODEM_POWER_IN: C27.1, C29.1, C30.1, C31.1, C32.1, Modem1.51 (VCC), Modem1.52 (VCC), Modem1.53 (VCC), R17.1; also elsewhere on the board
/Modem 3G/SIM_CLK: C25.2, Con1.C3 (CLK), D6.1 (A), Modem1.38 (SIM_CLK)
/Modem 3G/SIM_DET: Modem1.42 (SIM_DET), R10.1
/Modem 3G/SIM_IO: C26.2, Con1.C7 (IO), D7.1 (A), Modem1.39 (SIM_IO)
/Modem 3G/SIM_RST: C24.2, Con1.C2 (RST), D5.1 (A), Modem1.40 (SIM_RST)
/Modem 3G/VSIM: C23.2, Con1.C1 (VCC), D4.1 (A), Modem1.41 (VSIM)
/USB Hub Module/USB_D4_OUT_N: Modem1.28 (USB_D-); also elsewhere on the board
/USB Hub Module/USB_D4_OUT_P: Modem1.29 (USB_D+); also elsewhere on the board
GND: Ant1.0 (GND), C23.1, C24.1, C25.1, C26.1, C27.2, C28.2, C29.2, C30.2, C31.2, C32.2, Con1.C5 (GND), D4.2 (K), D5.2 (K), D6.2 (K), D7.2 (K), L4.2, Modem1.1 (GND), Modem1.3 (GND), Modem1.5 (GND), Modem1.14 (GND), Modem1.20 (GND), Modem1.21 (GND), Modem1.22 (GND), Modem1.30 (GND), Modem1.32 (GND), Modem1.33 (RSVD_GND), Modem1.43 (GND), Modem1.50 (GND), Modem1.54 (GND), Modem1.55 (GND), Modem1.57 (GND), Modem1.58 (GND), Modem1.59 (GND), Modem1.60 (GND), Modem1.61 (GND), Modem1.63 (GND), Modem1.64 (GND), Modem1.65 (GND), Modem1.66 (GND), Modem1.67 (GND), Modem1.68 (GND), Modem1.69 (GND), Modem1.70 (GND), Modem1.71 (GND), Modem1.72 (GND), Modem1.73 (GND), Modem1.74 (GND), Modem1.75 (GND), Modem1.76 (GND), Modem1.77 (GND), Modem1.78 (GND), Modem1.79 (GND), Modem1.80 (GND), Modem1.81 (GND), Modem1.82 (GND), Modem1.83 (GND), Modem1.84 (GND), Modem1.85 (GND), Modem1.86 (GND), Modem1.87 (GND), Modem1.88 (GND), Modem1.89 (GND), Modem1.90 (GND), Modem1.91 (GND), Modem1.92 (GND), Modem1.93 (GND), Modem1.94 (GND), Modem1.95 (GND), Modem1.96 (GND), Q1.2 (E), R11.2, R12.2, R16.2; also elsewhere on the board
unnamed: Ant1.1 (In), C33.1, L4.1
unnamed: C33.2, Modem1.56 (ANT)
unnamed: D8.1 (A), R17.2
unnamed: D8.2 (K), Q1.3 (C)
unnamed: Modem1.9 (DTR), R11.1
unnamed: Modem1.10 (RTS), R12.1
unnamed: Modem1.16 (GPIO1), R15.2
unnamed: Q1.1 (B), R15.1, R16.1

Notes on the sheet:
MODEM 3G GSM

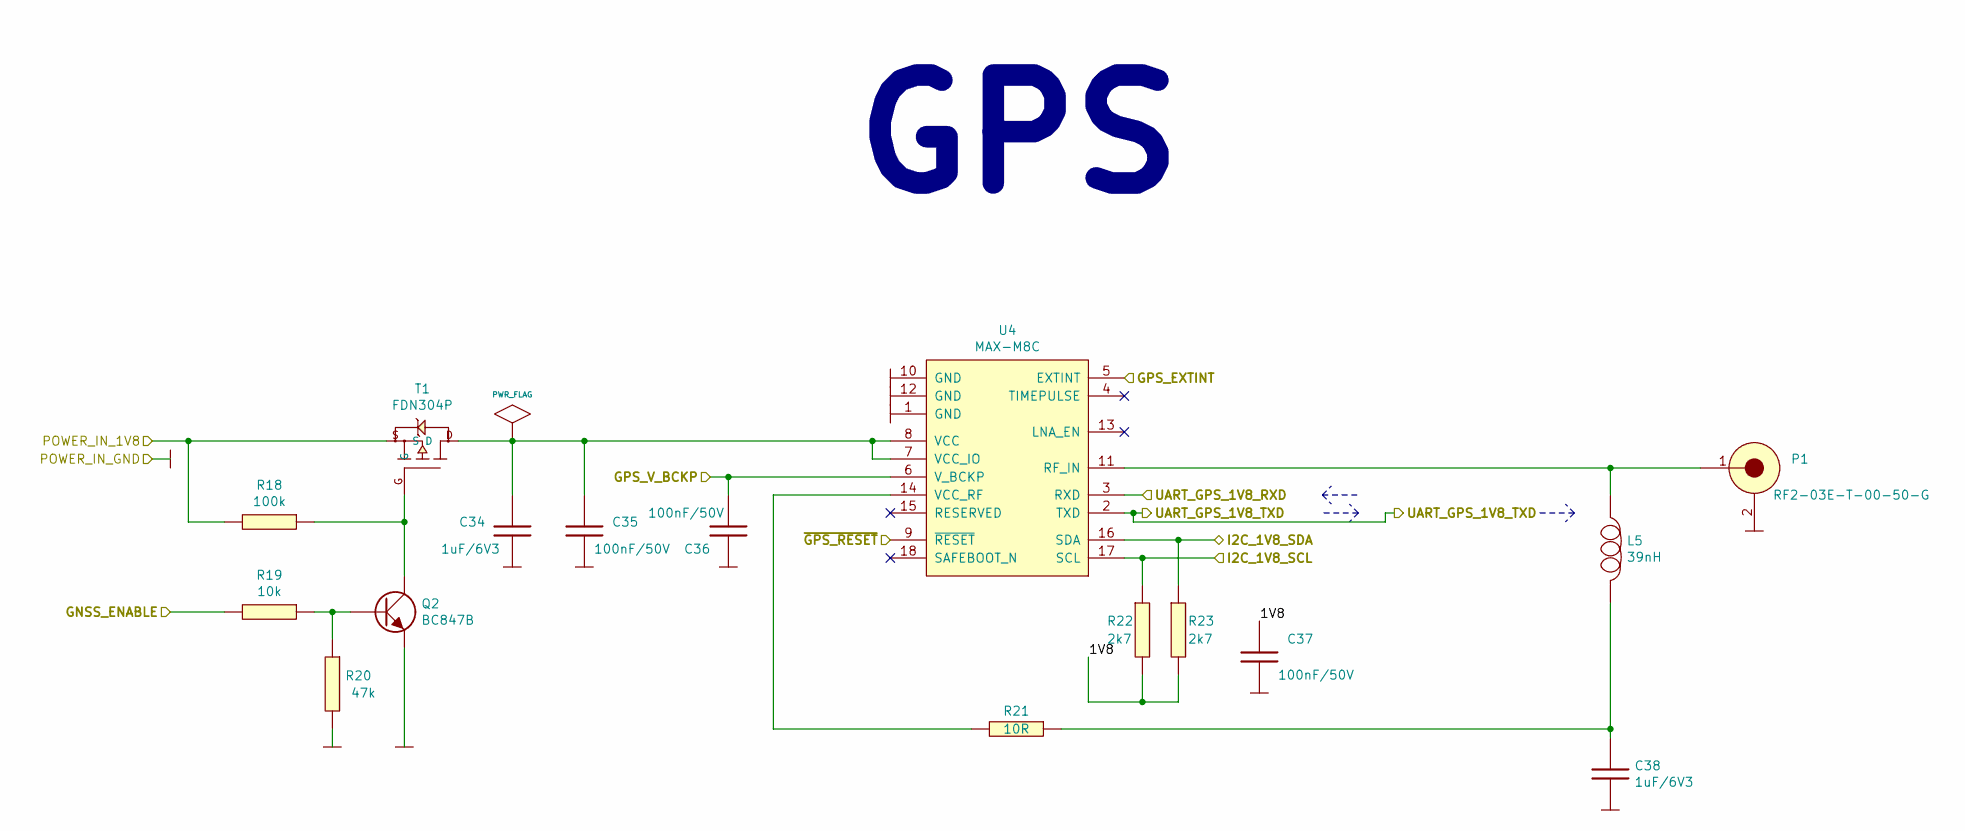
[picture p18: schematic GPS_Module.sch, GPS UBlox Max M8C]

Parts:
C34, C38: 1uF/6V3; 1uF_0603; Manufacturer Part Number CL10B105KO8NNNC
C35, C36, C37: 100nF/50V; 100nF_0402; Manufacturer Part Number CL05B104KO5NNNC
L5: 39nH; 39nH_0603; Manufacturer Part Number HK160839NH-T
P1: RF2-03E-T-00-50-G; Manufacturer Part Number RF2-03E-T-00-50-G
Q2: BC847B; BC847B_SOT23; Manufacturer Part Number BC847BE6327
R18: 100k; 100k_0402; Manufacturer Part Number RC0402FR-07100K
R19: 10k; 10k_0402; Manufacturer Part Number 0402WGF1002TCE
R20: 47k; 47k_0402; Manufacturer Part Number CQ02WGF4702TCE
R21: 10R; 10R_0402; Manufacturer Part Number 0402WGF100JTCE
R22, R23: 2k7; 2k7_0402; Manufacturer Part Number CRCW04022K70FKTDBC
T1: FDN304P; FDN304P_SOT23; Manufacturer Part Number FDN304P
U4: MAX-M8C; Max-M8C

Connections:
/GPS Module/1V8: C37.1, R22.2, R23.2
/GPS Module/GNSS_ENABLE: R19.2; also elsewhere on the board
/GPS Module/GPS_EXTINT: U4.5 (EXTINT); also elsewhere on the board
/GPS Module/GPS_V_BCKP: C36.1, U4.6 (V_BCKP); also elsewhere on the board
/GPS Module/POWER_IN_1V8: R18.2, T1.S; also elsewhere on the board
/LicheePi Nano SOM/GPIO_PD9: U4.9 (~RESET); also elsewhere on the board
/Logic Voltage Shifter/SIG1_LOW_PART: U4.3 (RXD); also elsewhere on the board
/Logic Voltage Shifter/SIG2_LOW_PART: U4.2 (TXD); also elsewhere on the board
/Modem 3G/GPS_I2C_1V8_SCL: R22.1, U4.17 (SCL); also elsewhere on the board
/Modem 3G/GPS_I2C_1V8_SDA: R23.1, U4.16 (SDA); also elsewhere on the board
GND: C34.2, C35.2, C36.2, C37.2, C38.2, P1.2 (GND), Q2.2 (E), R20.2, U4.1 (GND), U4.10 (GND), U4.12 (GND); also elsewhere on the board
unnamed: C34.1, C35.1, T1.D, U4.7 (VCC_IO), U4.8 (VCC)
unnamed: C38.1, L5.2, R21.1
unnamed: L5.1, P1.1 (SIGNAL), U4.11 (RF_IN)
unnamed: Q2.1 (B), R19.1, R20.1
unnamed: Q2.3 (C), R18.1, T1.G
unnamed: R21.2, U4.14 (VCC_RF)

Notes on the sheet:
GPS

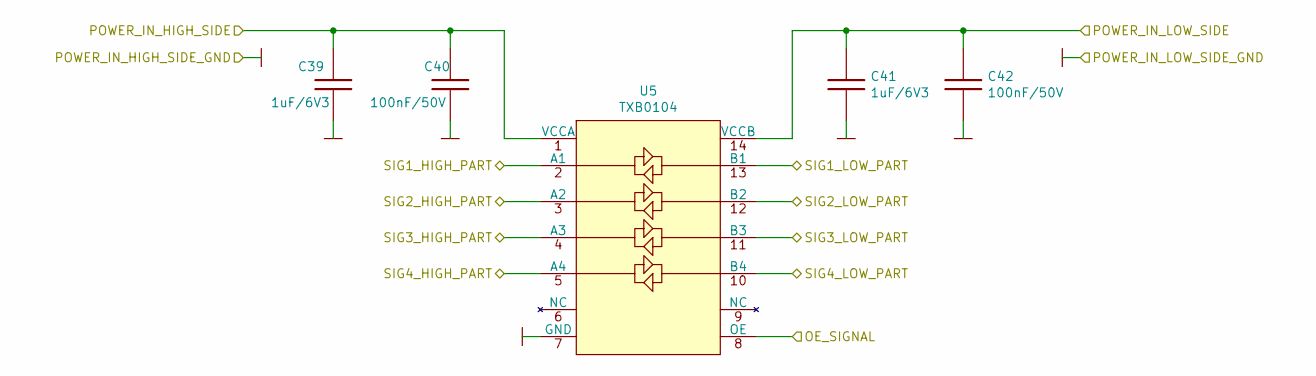
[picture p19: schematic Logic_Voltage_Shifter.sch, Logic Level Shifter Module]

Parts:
C39, C41: 1uF/6V3; 1uF_0603; Manufacturer Part Number CL10B105KO8NNNC
C40, C42: 100nF/50V; 100nF_0603; Manufacturer Part Number CL10B104JB8NNNC
U5: TXB0104; TXB0104_TSSOP14; Manufacturer Part Number TXB0104PWR; LCSC Part # (optional) C60708

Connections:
3V3: C39.1, C40.1, U5.1 (VCCA); also elsewhere on the board
/GPS Module/POWER_IN_1V8: C41.1, C42.1, U5.14 (VCCB); also elsewhere on the board
/LicheePi Nano SOM/GPIO_PD5: U5.8 (OE); also elsewhere on the board
/Logic Voltage Shifter/SIG1_HIGH_PART: U5.2 (A1); also elsewhere on the board
/Logic Voltage Shifter/SIG1_LOW_PART: U5.13 (B1); also elsewhere on the board
/Logic Voltage Shifter/SIG2_HIGH_PART: U5.3 (A2); also elsewhere on the board
/Logic Voltage Shifter/SIG2_LOW_PART: U5.12 (B2); also elsewhere on the board
/Logic Voltage Shifter/SIG3_HIGH_PART: U5.4 (A3); also elsewhere on the board
/Logic Voltage Shifter/SIG3_LOW_PART: U5.11 (B3); also elsewhere on the board
/Logic Voltage Shifter/SIG4_HIGH_PART: U5.5 (A4); also elsewhere on the board
/Logic Voltage Shifter/SIG4_LOW_PART: U5.10 (B4); also elsewhere on the board
GND: C39.2, C40.2, C41.2, C42.2, U5.7 (GND); also elsewhere on the board

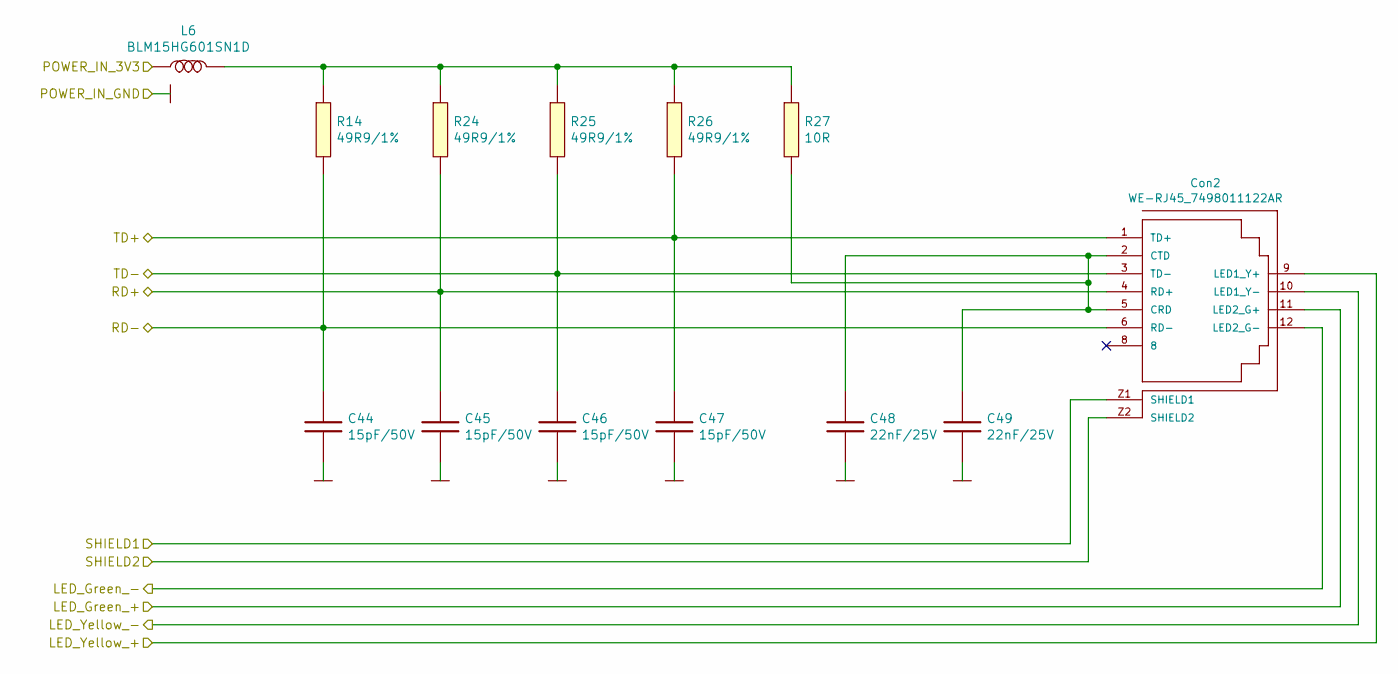
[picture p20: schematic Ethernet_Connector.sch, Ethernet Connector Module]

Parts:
C44, C45, C46, C47: 15pF/50V; 15pF_0402; Manufacturer Part Number GRM1555C1H150JA01D
C48, C49: 22nF/25V; 22nF_0402; Manufacturer Part Number GRM155R71E223KA61D
Con2: WE-RJ45_7498011122AR; Manufacturer Part Number 7498011122AR
L6: BLM15HG601SN1D; BLM15HG601SN1D_0402
R14, R24, R25, R26: 49R9/1%; 49R9_0402
R27: 10R; 10R_0402; Manufacturer Part Number 0402WGF100JTCE

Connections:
3V3: Con2.9 (LED1_Y+), Con2.11 (LED2_G+); also elsewhere on the board
/Ethernet Connector Module/LED_Green_-: Con2.12 (LED2_G-); also elsewhere on the board
/Ethernet Connector Module/LED_Yellow_-: Con2.10 (LED1_Y-); also elsewhere on the board
/Ethernet Connector Module/POWER_IN_3V3: L6.1; also elsewhere on the board
/Ethernet Connector Module/SHIELD1: Con2.Z1 (SHIELD1), Con2.Z2 (SHIELD2); also elsewhere on the board
/USB Hub Module/ETHERNET_RXN: C44.1, Con2.6 (RD-), R14.2; also elsewhere on the board
/USB Hub Module/ETHERNET_RXP: C45.1, Con2.4 (RD+), R24.2; also elsewhere on the board
/USB Hub Module/ETHERNET_TXN: C46.1, Con2.3 (TD-), R25.2; also elsewhere on the board
/USB Hub Module/ETHERNET_TXP: C47.1, Con2.1 (TD+), R26.2; also elsewhere on the board
GND: C44.2, C45.2, C46.2, C47.2, C48.2, C49.2; also elsewhere on the board
unnamed: C48.1, C49.1, Con2.2 (CTD), Con2.5 (CRD), R27.2
unnamed: L6.2, R14.1, R24.1, R25.1, R26.1, R27.1

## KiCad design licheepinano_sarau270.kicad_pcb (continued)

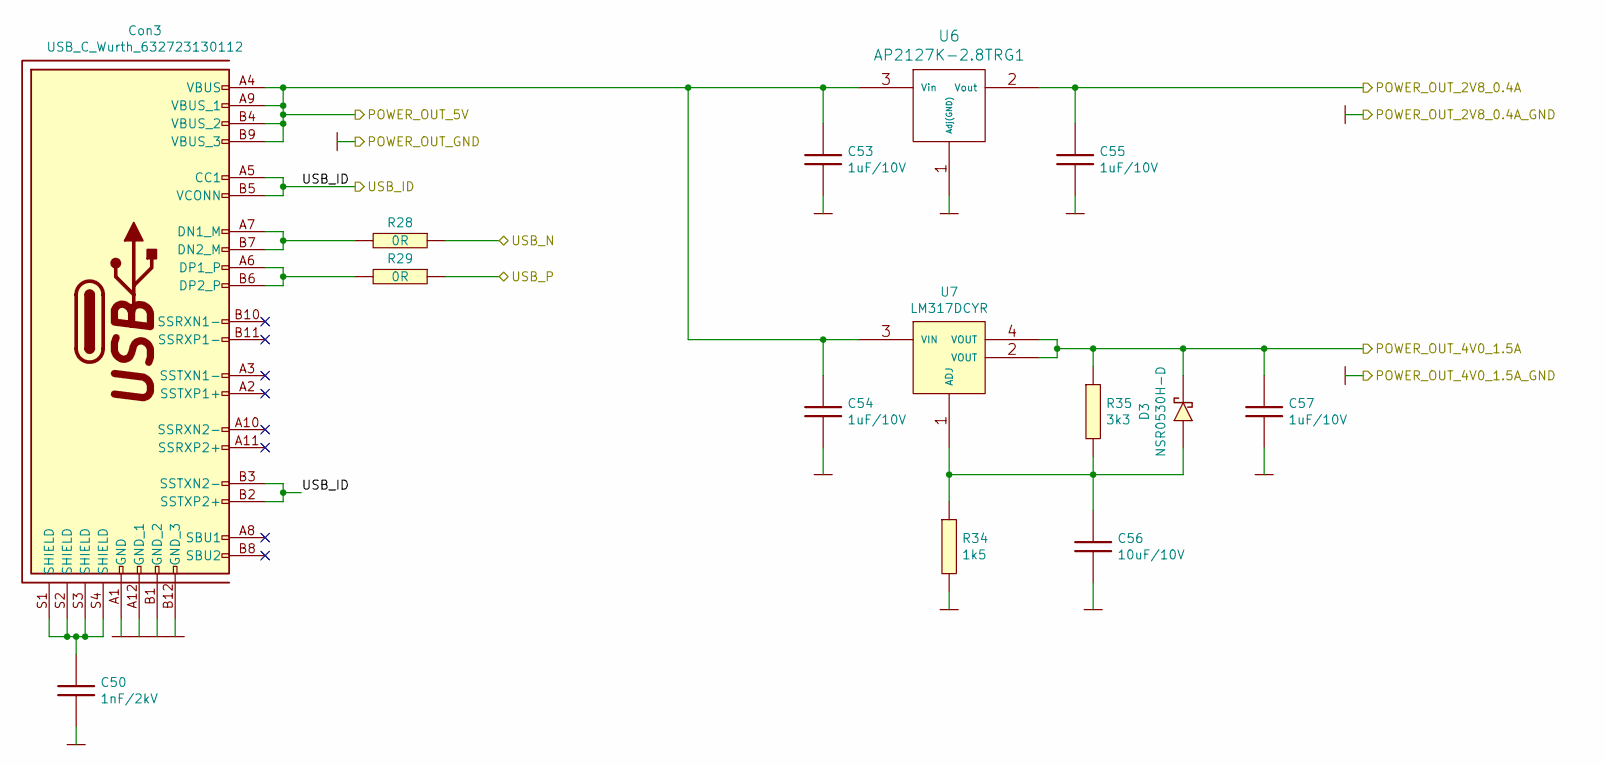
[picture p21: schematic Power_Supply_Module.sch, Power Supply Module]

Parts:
C50: 1nF/2kV; 1nF_2kV_1206; Manufacturer Part Number CC1206KKX7RDBB102
C53, C54, C55, C57: 1uF/10V; 1uF_0402; Manufacturer Part Number CL05A105KP5NNNC
C56: 10uF/10V; 10uF_10V_0603; Manufacturer Part Number C0603C106M9PACTU; LCSC Part # (optional) C162265
Con3: USB_C_Wurth_632723130112; USB_C_632723130112; Manufacturer Part Number 632723130112
D3: NSR0530H-D; NSR0530H-D_SOD323
R28, R29: 0R; 0R_0402; Manufacturer Part Number CRCW04020000Z0ED; LCSC Part # (optional) C325378
R34: 1k5; 1k5_0402; Manufacturer Part Number 0402WGF1501TCE
R35: 3k3; 3k3_0402; Manufacturer Part Number 0402WGF3301TCE
U6: AP2127K-2.8TRG1; AP2127K-2.8TRG1_SOT23; Manufacturer Part Number AP2127K-2.8TRG1; LCSC Part # (optional) C236686
U7: LM317DCYR; LM317DCYR_SOT223; Manufacturer Part Number LM317DCYR; LCSC Part # (optional) C51466

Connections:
/LCD Module/POWER_IN_2V8: C55.1, U6.2 (Vout); also elsewhere on the board
/LicheePi Nano SOM/POWER_IN_5V0: C53.1, C54.1, Con3.A4 (VBUS), Con3.A9 (VBUS_1), Con3.B4 (VBUS_2), Con3.B9 (VBUS_3), U6.3 (Vin), U7.3 (VIN); also elsewhere on the board
/LicheePi Nano SOM/USB_D_N: R28.1; also elsewhere on the board
/LicheePi Nano SOM/USB_D_P: R29.1; also elsewhere on the board
/LicheePi Nano SOM/USB_ID: Con3.A5 (CC1), Con3.B2 (SSTXP2+), Con3.B3 (SSTXN2-), Con3.B5 (VCONN); also elsewhere on the board
/Modem 3G/MODEM_POWER_IN: C57.1, D3.1 (K), R35.1, U7.2 (VOUT), U7.4 (VOUT); also elsewhere on the board
GND: C50.2, C53.2, C54.2, C55.2, C56.2, C57.2, Con3.A1 (GND), Con3.A12 (GND_1), Con3.B1 (GND_2), Con3.B12 (GND_3), R34.2, U6.1 (Adj(GND)); also elsewhere on the board
unnamed: C50.1, Con3.S1 (SHIELD), Con3.S2 (SHIELD), Con3.S3 (SHIELD), Con3.S4 (SHIELD)
unnamed: C56.1, D3.2 (A), R34.1, R35.2, U7.1 (ADJ)
unnamed: Con3.A6 (DP1_P), Con3.B6 (DP2_P), R29.2
unnamed: Con3.A7 (DN1_M), Con3.B7 (DN2_M), R28.2

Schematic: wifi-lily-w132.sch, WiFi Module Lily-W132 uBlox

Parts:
C51: 10uF/16V; 10uF_0805
C52: 100nF/16V; 100nF_0603
U3: LILY-W132; LILY_W132

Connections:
3V3: C51.1, C52.1, U3.8 (VCC_IO), U3.9 (VCC); also elsewhere on the board
/UBlox WiFi Lily W132/ENABLE: U3.14 (PD_N); also elsewhere on the board
/USB Hub Module/USB_D5_OUT_N: U3.24 (USB_DM); also elsewhere on the board
/USB Hub Module/USB_D5_OUT_P: U3.23 (USB_DP); also elsewhere on the board
GND: C51.2, C52.2, U3.0 (GND), U3.6 (GND1), U3.10 (GND2), U3.11 (GND3), U3.13 (GND4), U3.21 (GND5), U3.22 (SDIO_EN_N), U3.25 (GND6); also elsewhere on the board

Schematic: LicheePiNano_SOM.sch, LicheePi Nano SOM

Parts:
D2: KPG-1608SURKC-T; LED_KPG-1608SURKC-T; Manufacturer Part Number KPG-1608SURKC-T
R32: 470R; 470R_0402; Manufacturer Part Number 0402WGF4700TCE
SOM1: LicheePiNano; Manufacturer Part Number LicheePi Nano

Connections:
3V3: R32.1, SOM1.53 (3V3); also elsewhere on the board
/LCD Module/CLK: SOM1.14 (PE9/CSI_D6/UART2_RTS/SPI1_CLK); also elsewhere on the board
/LCD Module/CS: SOM1.10 (PE7/CSI_D4/UART2_TX/SPI1_CS); also elsewhere on the board
/LCD Module/DC: SOM1.34 (PD8/LCD_D12/DA_BCLK); also elsewhere on the board
/LCD Module/LED_A: SOM1.65 (VLED+); also elsewhere on the board
/LCD Module/LED_K1: SOM1.66 (VLED-); also elsewhere on the board
/LCD Module/MISO: SOM1.12 (PE8/CSI_D5/UART2_RX/SPI1_MOSI); also elsewhere on the board
/LCD Module/MOSI: SOM1.16 (PE10/CSI_D7/UART2_CTS/SPI1_MISO); also elsewhere on the board
/LicheePi Nano SOM/GPIO_PD0: SOM1.30 (PD0/LCD_D2/TWI0_SDA); also elsewhere on the board
/LicheePi Nano SOM/GPIO_PD1: SOM1.29 (PD1/LCD_D3/UART1_RTS); also elsewhere on the board
/LicheePi Nano SOM/GPIO_PD5: SOM1.25 (PD5/LCD_D7/TWI1_SCK); also elsewhere on the board
/LicheePi Nano SOM/GPIO_PD9: SOM1.33 (PD9/LCD_D13/DA_LRCK); also elsewhere on the board
/LicheePi Nano SOM/GPIO_PD11: SOM1.31 (PD11/LCD_D15/DA_OUT); also elsewhere on the board
/LicheePi Nano SOM/GPIO_PD19: SOM1.21 (PD19/LCD_DE/SPI0_MOSI); also elsewhere on the board
/LicheePi Nano SOM/POWER_IN_5V0: SOM1.57 (5V); also elsewhere on the board
/LicheePi Nano SOM/TPX1: SOM1.51 (PA0/TPX1/-/DA_BCLK/UART1_RTS/SPI1_CS); also elsewhere on the board
/LicheePi Nano SOM/TPX2: SOM1.49 (PA1/TPX2/-/DA_LRCK/UART1_CTS/SPI1_MOSI); also elsewhere on the board
/LicheePi Nano SOM/TPY1: SOM1.47 (PA2/TPY1/PWM0/DA_IN/UART1_RX/SPI1_CLK); also elsewhere on the board
/LicheePi Nano SOM/TPY2: SOM1.45 (PA3/TPY2/IR_RX/DA_OUT/UART1_TX/SPI1_MISO); also elsewhere on the board
/LicheePi Nano SOM/USB_D_N: SOM1.64 (USB_DM); also elsewhere on the board
/LicheePi Nano SOM/USB_D_P: SOM1.62 (USB_DP); also elsewhere on the board
/LicheePi Nano SOM/USB_ID: SOM1.63 (PE2/CSI_PCLK/LCD_D8/CLK_OUT); also elsewhere on the board
/Logic Voltage Shifter/SIG1_HIGH_PART: SOM1.41 (PD13/LCD_D19/UART2_TX); also elsewhere on the board
/Logic Voltage Shifter/SIG2_HIGH_PART: SOM1.40 (PD14/LCD_D20/UART2_RX); also elsewhere on the board
/Logic Voltage Shifter/SIG3_HIGH_PART: SOM1.26 (PD4/LCD_D6/UART1_TX); also elsewhere on the board
/Logic Voltage Shifter/SIG4_HIGH_PART: SOM1.27 (PD3/LCD_D5/UART1_RX); also elsewhere on the board
/UBlox WiFi Lily W132/ENABLE: SOM1.32 (PD10/LCD_D14/DA_IN); also elsewhere on the board
GND: SOM1.55 (GND); also elsewhere on the board
unnamed: D2.1 (A), R32.2
unnamed: D2.2 (K), SOM1.22 (PD21/LCD_VSYNC/SPI0_MISO)

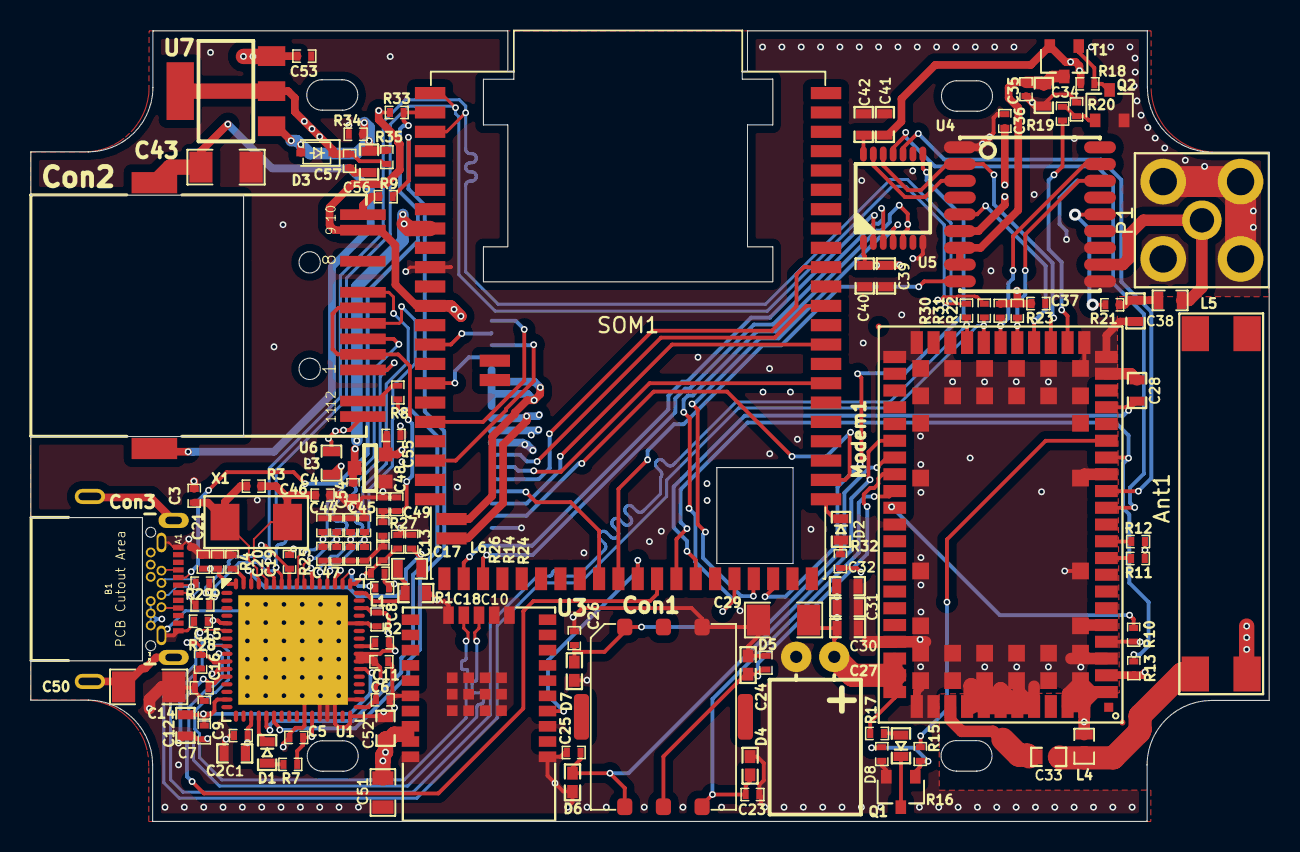
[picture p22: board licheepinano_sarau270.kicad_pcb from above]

Board: 4 copper layers, 81.3 x 51.9 mm, 120 parts (1 on the bottom side), 92 nets.

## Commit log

2020-11-15 Added Hub USB, Modem 3G and GPS
    [GPS_Module.sch, Lcd_Module.sch, LicheePiNano_SOM.sch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]
2020-11-21 Updated schematic
    [GPS_Module.sch, Modem_3G.sch, licheepinano_sarau270.sch]
2020-11-21 Added logic level shifter on pcb
    [Ethernet_Connector.sch, GPS_Module.sch, Lcd_Module.sch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]
2020-11-22 Continue connections on schematic
    [Logic_Voltage_Shifter.sch, Modem_3G.sch, licheepinano_sarau270.sch]
2020-11-28 Added ethernet connector on pcb
    [Ethernet_Connector.sch, licheepinano_sarau270.kicad_pcb]
2020-11-28 Added connection for ethernet modules
    [Ethernet_Connector.sch, Modem_3G.sch, Usb_Hub_Module.sch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]
2020-11-28 Added WiFi and figurated some components on pcb
    [Ethernet_Connector.sch, GPS_Module.sch, Lcd_Module.sch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]
2020-11-28 Schematic finished, with check ERC
    [Lcd_Module.sch, LicheePiNano_SOM.sch, Modem_3G.sch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]
2020-11-28 Updated README.md and figurated components on pcb
    [Ethernet_Connector.sch, GPS_Module.sch, Usb_Hub_Module.sch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]
2020-11-30 Added most of the pcb connections
    [licheepinano_sarau270.kicad_pcb]
2020-12-01 Added all connections, usb and ethernet track not aligned yet, component references not aligned, gerbers not generated
    [Power_Supply_Module.sch, licheepinano_sarau270.kicad_pcb, licheepinano_sarau270.sch]
2020-12-01 Aligned all sillks and generated BOM, Gerbser, Schematic PDF
    [licheepinano_sarau270-B_Cu.gbr, licheepinano_sarau270-B_Mask.gbr, licheepinano_sarau270-B_Paste.gbr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]
2020-12-01 Tuned high speed tracks
    [licheepinano_sarau270-B_Cu.gbr, licheepinano_sarau270-B_Mask.gbr, licheepinano_sarau270-B_Paste.gbr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]
2020-12-08 Rotate sim card holder
    [licheepinano_sarau270-B_Cu.gbr, licheepinano_sarau270-B_Mask.gbr, licheepinano_sarau270-B_Paste.gbr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]
2021-01-03 Applied all issues
    [licheepinano_sarau270-B_Cu.gbr, licheepinano_sarau270-B_Mask.gbr, licheepinano_sarau270-B_Paste.gbr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]
